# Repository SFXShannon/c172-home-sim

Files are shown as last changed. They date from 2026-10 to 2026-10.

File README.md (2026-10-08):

# C172 Home Sim

3D-printable cockpit controls modelled on the Cessna 172, and a full **172S G1000 dashboard** to mount them in. They're built to drive MSFS from a home-built cockpit.

The goal is **parts that look like the real aircraft's, with simple insides**: printed parts, a few screws, and off-the-shelf sensors such as tactile switches, encoders, slide pots, rockers and toggles.

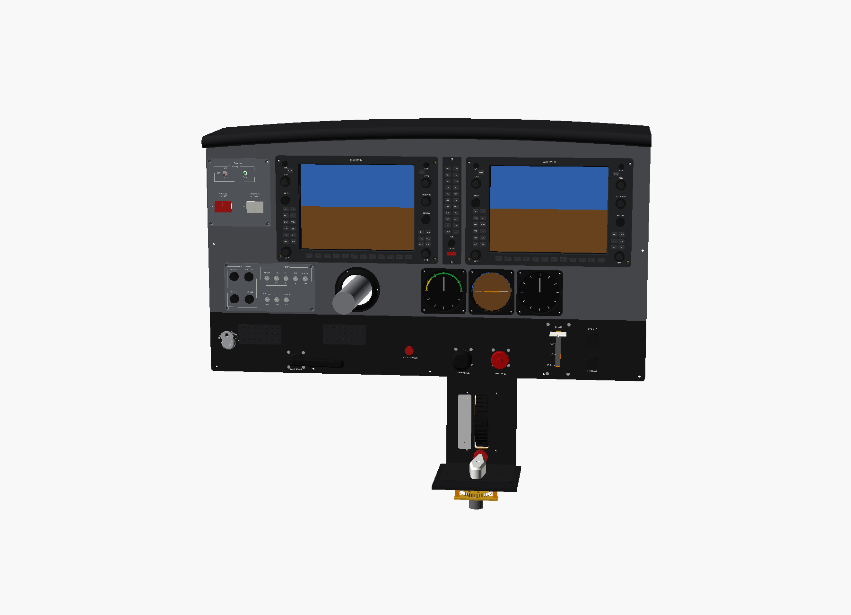
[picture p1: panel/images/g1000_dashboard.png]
G1000 dashboard


**The G1000 dashboard** ([`panel/`](panel#g1000-dashboard)) is a 172S NAV III panel at real scale, shortened to about 32" (810 mm):

- **Glass:** working PFD and MFD bezels with every real key and knob, each with a 10.4" screen behind it, and a working GMA 1347 audio panel.
- **Switches:** the real C-post and lights panels, and the standby instruments.
- **Lower panel:** ignition key, throttle, mixture, flaps, parking brake and cabin knobs.
- **Pedestal:** trim wheel and fuel selector.
- **Yoke:** an opening for the Moza AY210 shaft.

It prints as 9 tiles sized for a 305 mm bed (QIDI Plus4). On a smaller printer, change `bed` and the seams; OpenSCAD warns if a tile won't fit. Or [cut it on a CNC router](panel/dashboard/cnc) from 1/4" plywood in 4 pieces (fits an 800 × 400 mm router such as the FoxAlien XE-PRO 8040).

## See them work

Each animation shows the control from the pilot's seat (left) and from behind the panel with the housing see-through (right), so you can watch the mechanism move. The bezels and switch panels show a close-up on the right instead.

**Parking brake**: pull out, rotate down to set, the lug drops into its notch; rotate back up and the spring pulls it home.

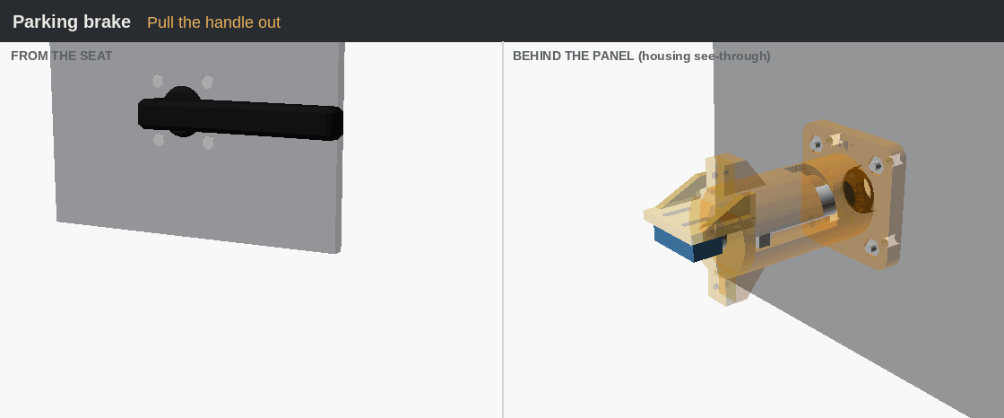
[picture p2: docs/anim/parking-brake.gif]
Parking brake working


**Throttle**: the 8 mm rod slides through the housing and the carriage moves the slide pot. The mixture and prop work the same way.

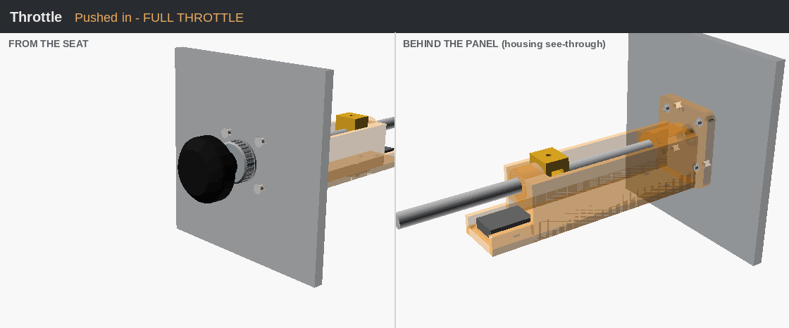
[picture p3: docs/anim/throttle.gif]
Throttle working


**Mixture**

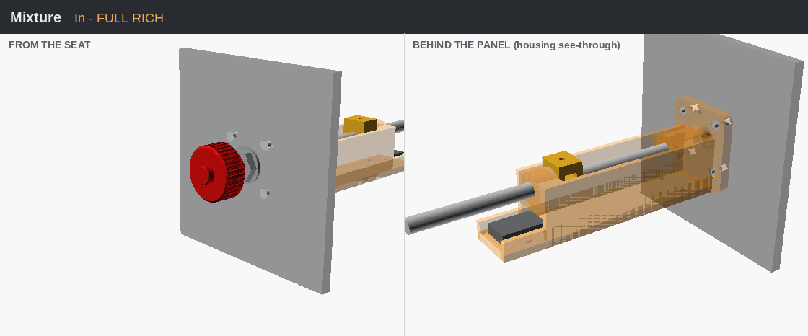
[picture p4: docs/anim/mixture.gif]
Mixture working


**Prop** (optional)

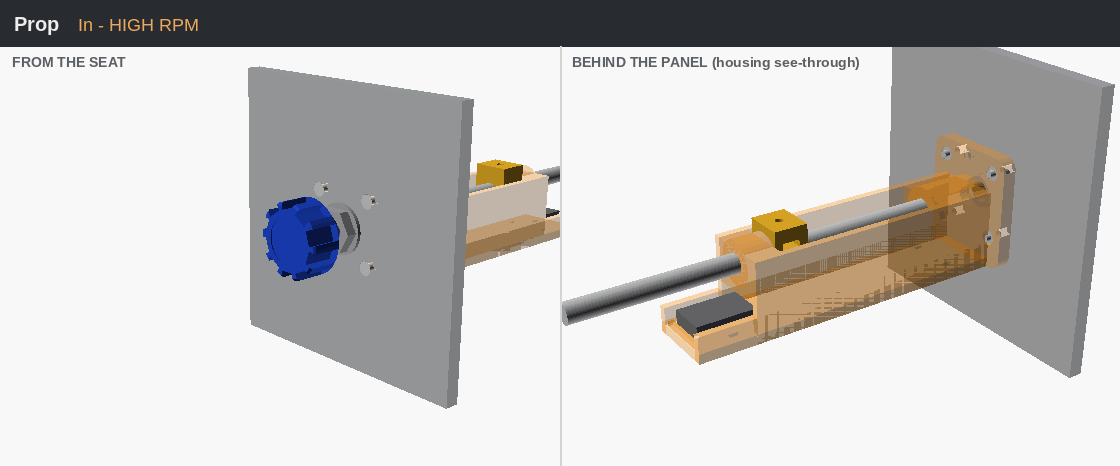
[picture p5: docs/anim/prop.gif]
Prop working


**Elevator trim wheel**: roll the top forward for nose down, back for nose up. The gear on the side of the wheel spins the encoder 3× as fast.

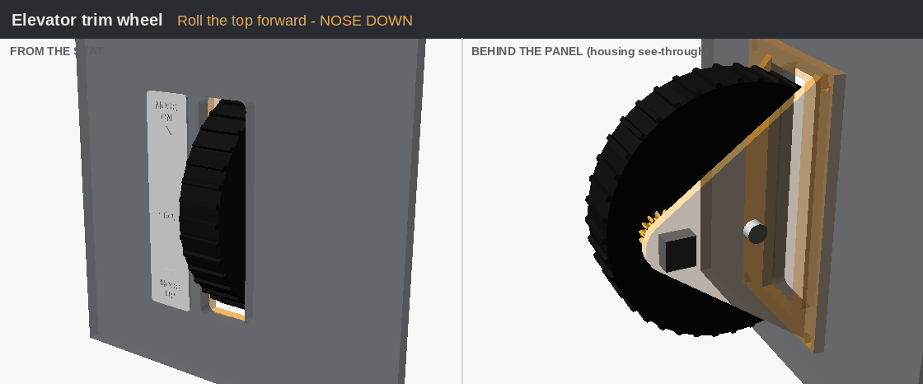
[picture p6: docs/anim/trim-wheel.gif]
Trim wheel working


**Fuel selector**: BOTH → LEFT → BOTH → RIGHT. The small gear on the handle turns the big gear on the rotary switch 1/3 as far, so the handle clicks once per tank position.

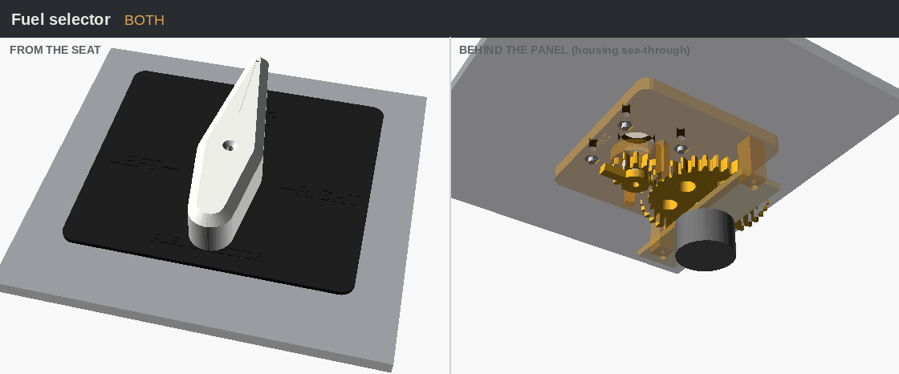
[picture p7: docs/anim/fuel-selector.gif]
Fuel selector working


**Flap lever**: push the handle down through UP → 10° → 20° → FULL. A springy finger on the carriage clicks into a notch at each stop, and the carriage slides a pot like the throttle's.

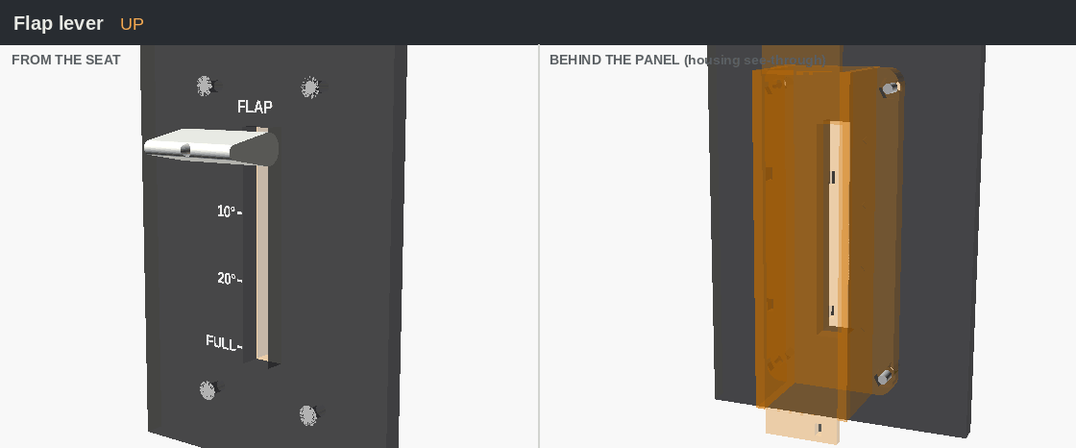
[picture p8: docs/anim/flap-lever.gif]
Flap lever working


**G1000 PFD / MFD bezel**: every key cap is a printed T-shape that presses a 6 mm tactile switch on the plate behind; each knob is an EC11 encoder, and the dual knobs are ALPS dual-shaft encoders. Keys are shown lit while pressed.

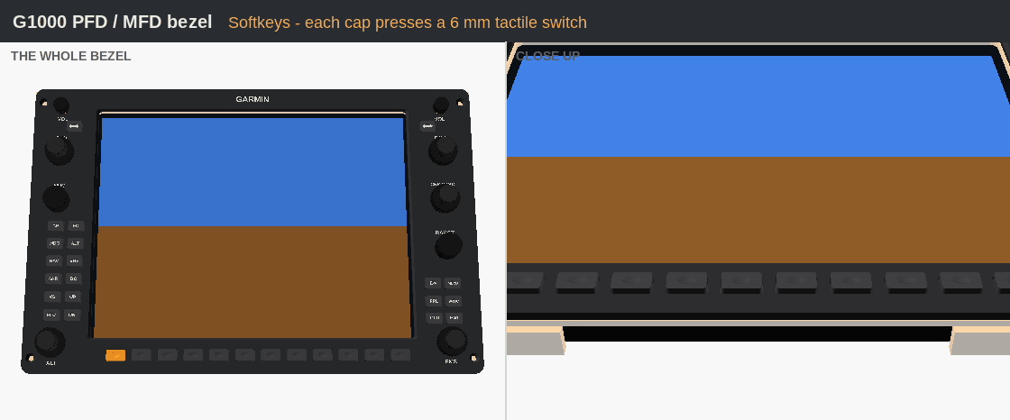
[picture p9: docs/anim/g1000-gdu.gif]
G1000 bezel working


**GMA 1347 audio panel**: same keys and encoder as the G1000 bezel.

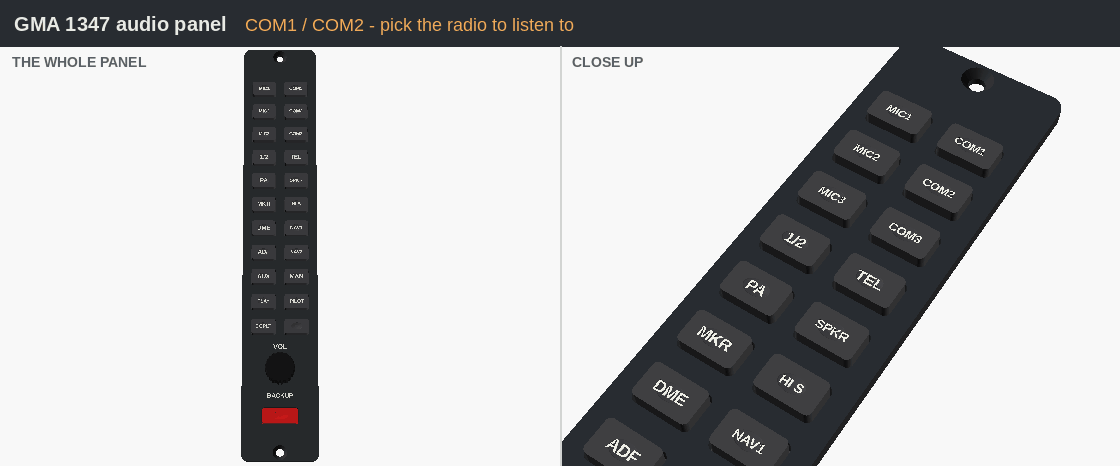
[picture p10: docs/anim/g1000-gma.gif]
Audio panel working


**C-post and lights panels**: off-the-shelf rockers for MASTER and AVIONICS, mini toggles for STBY BATT, lights, fuel pump and pitot heat, and 16 mm pots for the dimmers.

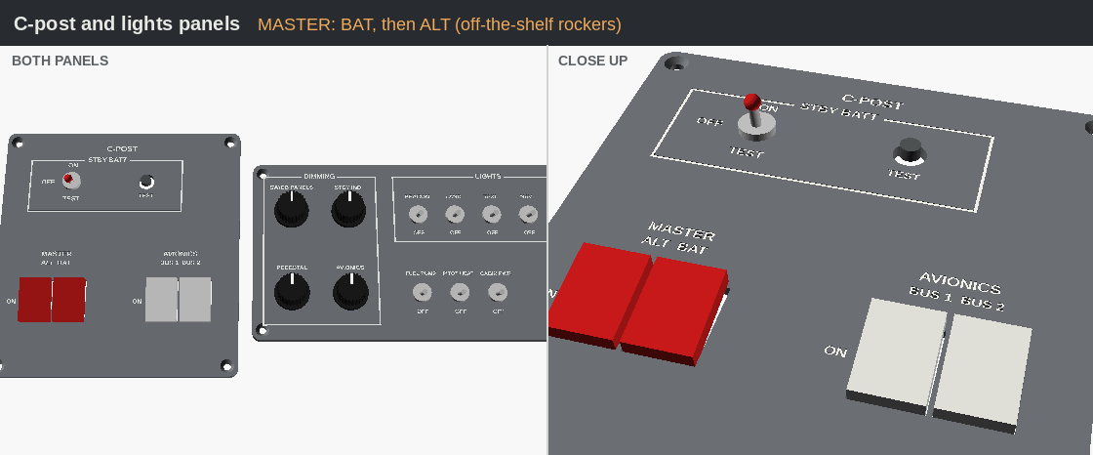
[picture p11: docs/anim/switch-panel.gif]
Switch panels working


**Ignition key**: OFF → R → L → BOTH → START on a rotary switch. The real key springs back from START; this one you turn back to BOTH yourself.

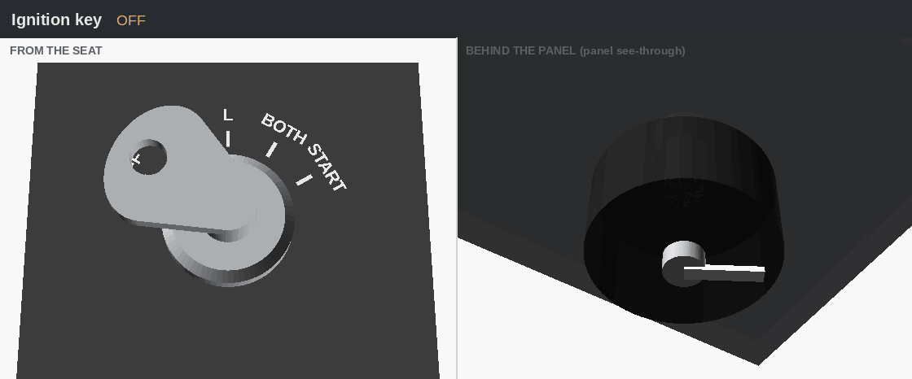
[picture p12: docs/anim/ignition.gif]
Ignition key working


## Controls

| Control | Looks like | Inside | Sensor |
|---|---|---|---|
| [Parking brake](parts/parking-brake) | Black L-lever; pull and rotate down to set | Spring + bayonet slot | Microswitch |
| [Throttle](parts/throttle) | Smooth round knob, knurled friction nut | 8 mm rod, O-ring friction | 128 mm slide pot (100 mm travel) |
| [Mixture](parts/mixture) | Red ribbed vernier knob with lock button | Same as throttle | 128 mm slide pot (100 mm travel) |
| [Prop](parts/prop) (optional) | Blue crenellated knob | Same as throttle | 128 mm slide pot (100 mm travel) |
| [Elevator trim wheel](parts/trim-wheel) | Black ridged wheel in the pedestal, NOSE DN / T.O. / NOSE UP placard | 608 bearings, 3:1 gear | EC11 encoder |
| [Fuel selector](parts/fuel-selector) | Pointer handle on a LEFT / BOTH / RIGHT placard | 3:1 gear to rotary switch | 1P12T rotary switch |
| [Flap lever](parts/flap-lever) | White flap handle, UP / 10 / 20 / FULL scale | Slide with 4 detent clicks | 128 mm slide pot (100 mm travel) |
| [G1000 PFD / MFD](parts/g1000-gdu) | Garmin GDU 1040 bezel, real size and key layout | Printed caps on tactile switches, 10.4" screen | 32 keys, 9 knobs (EC11 / dual EC11) |
| [Audio panel](parts/g1000-gma) | Garmin GMA 1347 | Same as the G1000 bezel | 22 keys, 1 knob |
| [Switch panels](parts/switch-panel) | C-post (STBY BATT, MASTER, AVIONICS) and lights / dimming | Off-the-shelf rockers, toggles and pots | 18 switches, 4 pots |
| [Standby gauges](parts/standby-gauges) | Airspeed, attitude, altimeter with 172S markings | Printed case, paper face | — (look only) |
| [Panel extras](parts/panel-extras) | Ignition key, ALT STATIC / CABIN HT / AIR / FUEL SHUTOFF knobs, breakers, yoke boot | | Rotary switch (key) |
| [Panels](panel) | **G1000 dashboard**, or the simple lower panel + pedestal | Tiled for printing | — |
| [Firmware](firmware) | Pro Micro joystick sketch + [G1000 wiring and MobiFlight guide](firmware/G1000_WIRING.md) | | Pro Micro + 3 × Arduino Mega |

The Moza AY210 yoke has its own buttons and hats, so those aren't modelled. With the base behind the dashboard, its 13-switch panel is out of reach, so the C-post and lights panels take over.

## Panel mounting (same for every control)

Every control bolts behind the panel the same way. Four **M3 countersunk screws** go in from the front, through the control's flange, into **M3 nuts captured in the back of the flange**. The screw heads sit flush, like the real panel. Each control folder has a `panel-template/` (SVG to print 1:1, DXF for laser/CNC) and a `panel_test_plate` STL for test-fitting.

## Moving the controls

On the **G1000 dashboard**, every position is a setting near the top of [`panel/g1000_dashboard.scad`](panel/g1000_dashboard.scad); see [its README](panel#changing-the-layout). The guide below is for the **simple lower panel**, which also has the drag-and-drop layout page.

Every control on the simple printable panel can be moved. The positions are plain numbers in [`panel/c172_panel.scad`](panel/c172_panel.scad). Change them, re-render, and the panel cutouts, countersinks and labels all move with them.

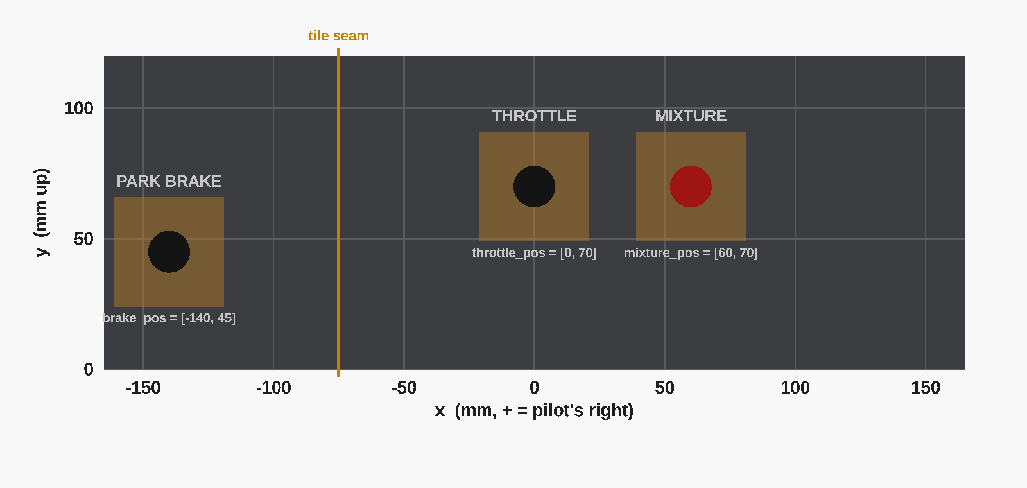
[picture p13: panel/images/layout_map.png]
Layout map


The numbers are in millimetres, as seen from the pilot's seat:
- **x** is how far right of the panel centre (negative = left).
- **y** is how far up from the bottom edge of the panel.

Each control's position is the centre of its knob or shaft.

### What you can move

| Setting | What it moves | Default |
|---|---|---|
| `brake_pos` | Parking brake | `[-140, 45]` |
| `throttle_pos` | Throttle | `[0, 70]` |
| `mixture_pos` | Mixture | `[60, 70]` |
| `mixture_pos_with_prop` | Mixture, used instead when `has_prop = true` | `[110, 70]` |
| `prop_pos` | Prop (only when `has_prop = true`) | `[55, 70]` |
| `has_prop` | Adds the prop control between the throttle and mixture | `false` |
| `pedestal_x` | Moves the whole pedestal (trim wheel + fuel selector) left/right | `30` |
| `lower_w`, `lower_h` | Size of the lower panel | `330`, `120` |
| `pedestal_w`, `pedestal_h`, `floor_d` | Size of the pedestal face and floor plate | `130`, `170`, `150` |
| `yoke_hole` | Cuts a yoke-shaft opening: `[x, y, width, height]`, or `[]` for none | `[]` |
| `labels` | Engraved THROTTLE / MIXTURE / ... labels on or off | `true` |
| `lower_splits` | Where the lower panel is split into print tiles (x positions) | `[-75]` |
| `bed` | Your printer's bed size, so tiles are checked to fit | `305` (QIDI Plus4) |

### Easiest: drag them around in the layout page

Download [`tools/panel-layout.html`](tools/panel-layout.html) (*Raw* → save) and open it in your browser.

- Drag the controls, the pedestal, the tile seams and the yoke opening on a to-scale drawing of the panel.
- It runs the same checks as the OpenSCAD file as you drag (overlaps, edges, seams, bed size). It also warns if the parking brake handle would swing into a knob or hang in front of the pedestal.
- Press **Copy settings** and paste the lines over the layout section of `panel/c172_panel.scad`, then run `scripts/render.sh panel`.
- It can also load the settings from your current file, so you can keep tweaking an existing layout.

### Or in OpenSCAD's Customizer

1. Install [OpenSCAD](https://openscad.org) and open `panel/c172_panel.scad`.
2. Open *Window → Customizer*. The settings above appear under **Layout - lower panel**, **Layout - pedestal** and **Printing**.
3. Change a value, for example `throttle_pos` to `[-10, 75]`. Press **F5** to see the whole cockpit with every control in its new place.
4. Check the console at the bottom for a **WARNING**. The file checks itself and warns if:
   - two controls are too close (their flanges behind the panel need about **46 mm** between centres),
   - a control hangs off the edge of the panel (keep it at least **21 mm** from every edge),
   - a tile seam cuts through a control (move the seam in `lower_splits`),
   - a tile is wider than your bed.
5. When it looks right, pick a piece in `part` (e.g. `lower_tile_1`), press **F6** to render, then **File → Export → STL**. Repeat for each piece you need.

### Or from the command line

Edit the numbers in the file, then rebuild every panel STL, the templates and the preview images:

```bash
scripts/render.sh panel
```

You can also try a layout without editing the file:

```bash
openscad -D 'throttle_pos=[-10,75]' -D 'mixture_pos=[55,75]' -D 'part="preview"' -o test.png panel/c172_panel.scad
```

### Tips

- **Match the sim cockpit.** In VR it matters more than anything that the real knob sits where your hand sees the virtual one. Measure from the sim's cockpit (or your yoke) and move the controls to match.
- **Adding a split:** if you make the panel wider, add more tile seams, e.g. `lower_splits = [-75, 90]`. The panel can be split into up to 3 tiles (`lower_tile_1` to `lower_tile_3`). Put each seam in a gap between controls.
- **Leave the trim wheel and fuel selector on the pedestal.** To move them, change `pedestal_x`, `pedestal_w`, `pedestal_h` or `floor_d`; the parts stay centred on their plates.
- **Pre-made controls.** The individual controls (`parts/...`) don't need re-rendering when you move them; only the panel changes.

## Layout

```
common/            shared settings (panel thickness, fit, M3 hardware, mount pattern, gears)
  push_pull.scad   shared throttle / mixture / prop mechanism
parts/<control>/
  <control>.scad   parametric source (OpenSCAD Customizer)
  stl/             print-ready STLs, already in print orientation
  panel-template/  cutout drawing
  images/          renders
  README.md        parts list, printing, assembly, wiring, MSFS binding
panel/             g1000_dashboard.scad (full dashboard) + c172_panel.scad (simple lower panel)
  dashboard/       dashboard tiles, glareshield, pedestal STLs + full-size templates
    cnc/           CNC router files (layered DXF / SVG) for cutting the panel from 1/4" sheet
firmware/          Arduino Pro Micro sketch, G1000 wiring / MobiFlight guide (G1000_WIRING.md)
tools/             panel-layout.html: drag-and-drop panel layout page
scripts/render.sh  regenerate STLs/templates for the controls
scripts/make_cnc.py  regenerate the CNC router files
scripts/place_splices.py  find room for the splice plates that join the panel pieces
```

## Rebuilding after changes

```bash
scripts/render.sh                  # all controls + both panels
scripts/render.sh throttle         # one control
scripts/render.sh dashboard        # the G1000 dashboard tiles, glareshield, pedestal
scripts/render.sh panel            # the simple lower panel
PANEL=3 scripts/render.sh          # for a 3 mm panel
```

Everything needs OpenSCAD 2021.01 or newer. To re-make the animations above after a change, run `python3 scripts/make_gifs.py` (needs Pillow). The script runs on Linux, macOS, or Windows with Git Bash or WSL.

## Status

Every moving part has been checked in OpenSCAD for collisions through its full range of movement, but **nothing has been test-printed yet**. Expect to tune `clearance` for your printer. Dimensions are approximated from photos of real 172 parts, not factory drawings.

## License

MIT. See [LICENSE](LICENSE).

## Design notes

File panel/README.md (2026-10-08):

# Printable Panels

There are two panel options:

1. **[G1000 dashboard](#g1000-dashboard)**: the full 172S G1000 panel, shortened to about 32" (810 mm), with every control. This is the main one.
2. **[Simple lower panel](#simple-lower-panel)**: just the parking brake, throttle, mixture (and prop) plus the pedestal. Good for testing the controls before building the whole dashboard.

---

## G1000 dashboard

G1000 dashboard

| Behind the panel (AY210 base shown as a grey box) | Layout and print tiles |
|---|---|
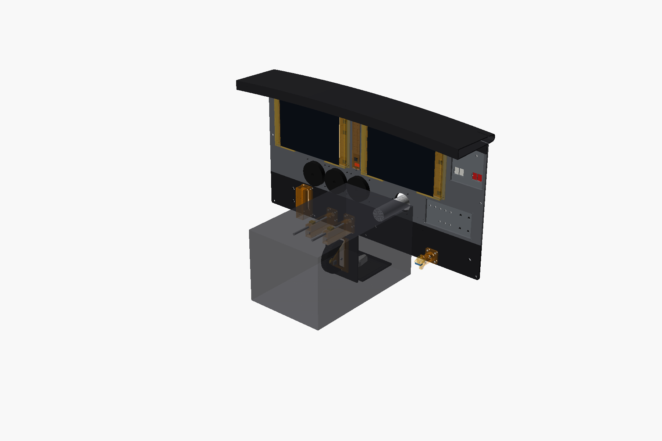
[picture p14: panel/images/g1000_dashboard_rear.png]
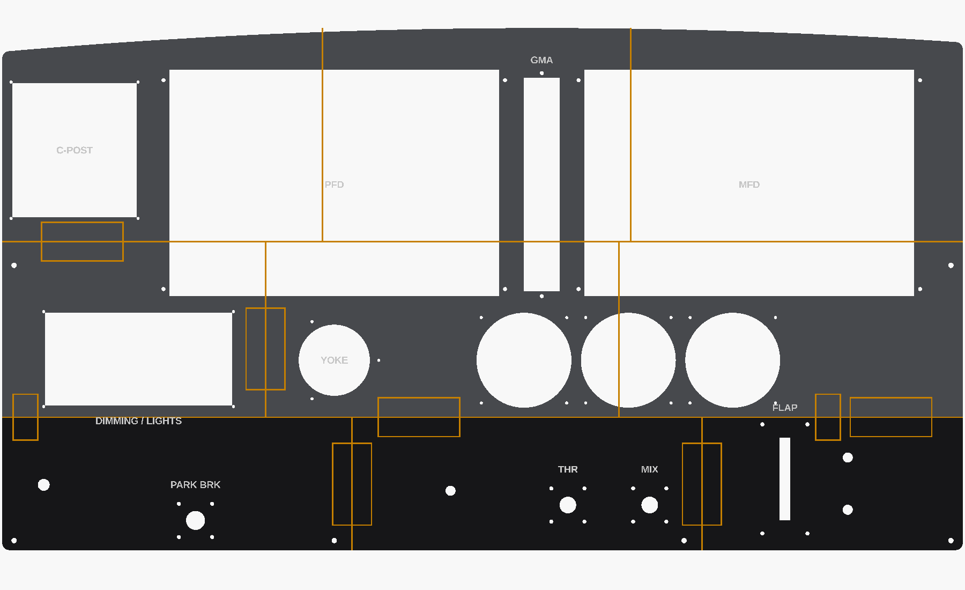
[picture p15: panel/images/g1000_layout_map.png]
|  |  |

Laid out from photos of the real 172S NAV III panel and kept at real scale; only the copilot side is cut off.

| Area | What's there |
|---|---|
| Upper (grey) | C-post switches, PFD, GMA 1347 audio panel, MFD, dimming/lights panel, yoke shaft opening, standby airspeed / attitude / altimeter |
| Lower (black) | Ignition key, circuit breakers (look only), parking brake, ALT STATIC AIR, throttle, mixture, flap lever, cabin heat / cabin air |
| Pedestal | Elevator trim wheel, fuel shutoff knob, floor plate with the fuel selector |
| Top | Glareshield in 4 segments |

### Printing it

- **Tiles:** 9 of them, 3 per row, sized for a 305 × 305 mm bed (QIDI Plus4). Row L (lower) in black; rows M and U in grey. Print them **front face down**. The largest is 298 × 148 mm. For a smaller printer, set `bed` and move the seams in `lower_splits`, `mid_splits` and `upper_splits` (up to 5 tiles per row); OpenSCAD warns if a tile is too wide.
- **Joining:** see [Joining the pieces](#joining-the-pieces) below.
- **Or cut it on a CNC router:** [`dashboard/cnc`](dashboard/cnc) has layered DXF / SVG files for cutting the panel from 1/4" plywood or MDF in 4 pieces (plus the pedestal plates), sized for an 800 × 400 mm router like the FoxAlien XE-PRO 8040.
- **Glareshield:** 4 segments. Print them upside down with tree supports, or use them as formers and cover with foam and vinyl like the real padded one.
- **Pedestal:** the face and floor plates.
- **Full-size template:** [`dashboard/templates/`](dashboard/templates) has the whole panel as one SVG/DXF (front view), for a big laser or to print and check the layout.
- **Mounting to your frame:** 4.5 mm holes along the bottom edge and the sides take #8 / M4 screws.

STLs are in [`dashboard/stl/`](dashboard/stl). After changing anything, regenerate them with `scripts/render.sh dashboard`.

### Fitting it to your Moza AY210

The yoke shaft comes through a 60 mm hole in front of the pilot (`yoke_pos`, default 160 mm up from the panel bottom), with a printed boot ring round it.

- **Shaft height:** set `moza_shaft_h` to the height of the AY210 shaft above the bottom of its base. Measure yours: Moza doesn't publish it, and the default 150 mm is a guess. Then set the panel height so the hole lines up with the shaft.
- **Clearance:** the base sits behind the panel. `moza_front` is the gap from the panel back to the base's front face; keep it above about 80 mm so the parking brake and the PFD screen clear it. The file warns if they'd collide.
- **Base switches:** the AY210's own 13-switch panel will be out of reach behind the dashboard, so the C-post and lights panel take over.

### Changing the layout

Every position is a setting near the top of [`g1000_dashboard.scad`](g1000_dashboard.scad), in mm from the pilot's centre line (`x`, + = right) and up from the panel bottom (`y`): `pfd_pos`, `gma_pos`, `mfd_pos`, `cpost_pos`, `lights_pos`, `gauge_*`, `yoke_pos`, `ignition_pos`, `brake_pos`, `throttle_pos`, `mixture_pos`, `flap_pos`, and so on. You can also change the panel width (`x_left`, `x_right`), the top arch, the tile seams and your `bed` size. OpenSCAD warns if a tile won't fit your printer.

---

## Joining the pieces

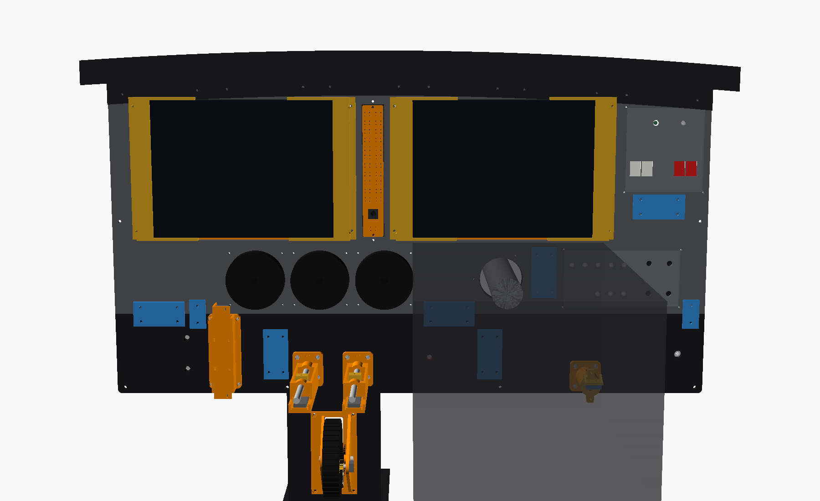
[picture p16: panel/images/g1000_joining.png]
Back of the dashboard: splice plates in blue


The tiles (or CNC pieces) butt together and are joined from the back in three ways:

1. **Splice plates** (blue above) straddle the seams and the two row joints. Each screws into **blind pilot holes** already in the back of the pieces, so nothing shows on the front. `scripts/place_splices.py` finds room for them clear of everything mounted behind the panel and writes their positions to [`splices.scad`](splices.scad). For the printed tiles that's:
   - 6 × `splice` (34 × 70 mm, 4 screws), across the lower seams, the seam beside the yoke, and the two row joints
   - 2 × `splice_small` (40 × 22 mm, 2 screws), for tight spots on the lower/middle row joint

   Print them flat, 4 mm thick (`panel/dashboard/stl/splice.stl`, `splice_small.stl`). Spread glue on the plate (CA or epoxy for PLA/PETG), press it on over its holes, and drive **M3 × 8** screws (4 mm into the panel; longer ones come through the front). The same plate turns 90° for the horizontal joints.
2. **The bezels and gauges** cover the seams that have no room for a plate (through the PFD, the MFD and the attitude gauge). Their screws go into the pieces on both sides, so each one acts as a splice.
3. **The glareshield** is split at different places from the upper tiles (`glareshield_splits`; by default halfway along each tile). Each glareshield piece screws into the tiles on both sides of a seam, which ties the top edge.

**Order:** lay the tiles face down on a flat table and glue and screw the splice plates. Then stand the panel up and fit the bezels, gauges and glareshield. Last, screw the panel to your frame through the frame holes along the bottom and sides.

If you move controls or change the seams, run `python3 scripts/place_splices.py` (needs `pip install shapely`) before re-rendering; `scripts/render.sh dashboard` does it for you. It prints each seam's plates, and says when a seam has no room for one.

## Simple lower panel

Panel pieces with every control's cutouts, mounting holes and countersinks already in place. The layout follows the 172S lower panel and centre pedestal.

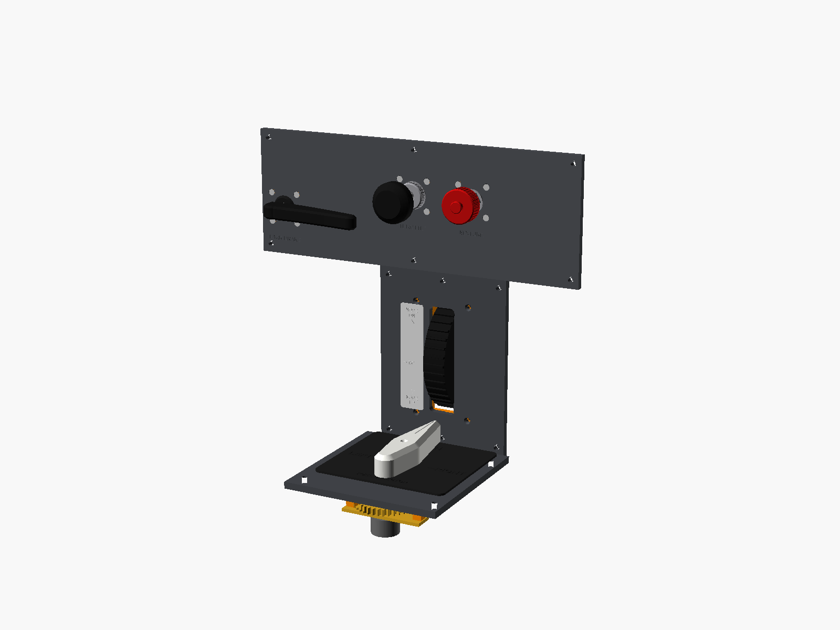
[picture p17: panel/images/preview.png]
preview


| With the optional prop control | Behind the panel |
|---|---|
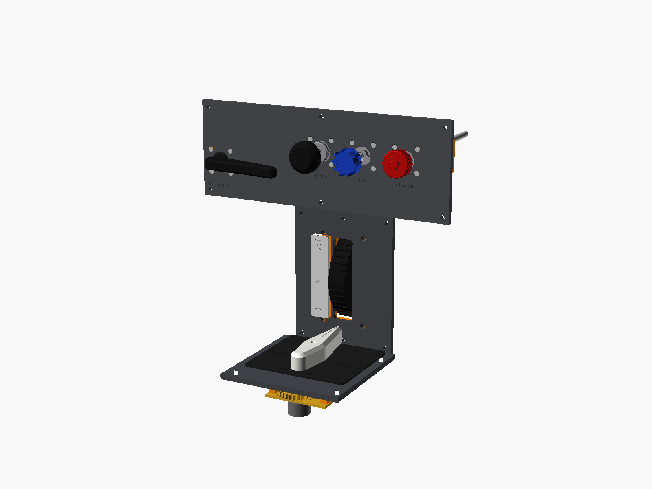
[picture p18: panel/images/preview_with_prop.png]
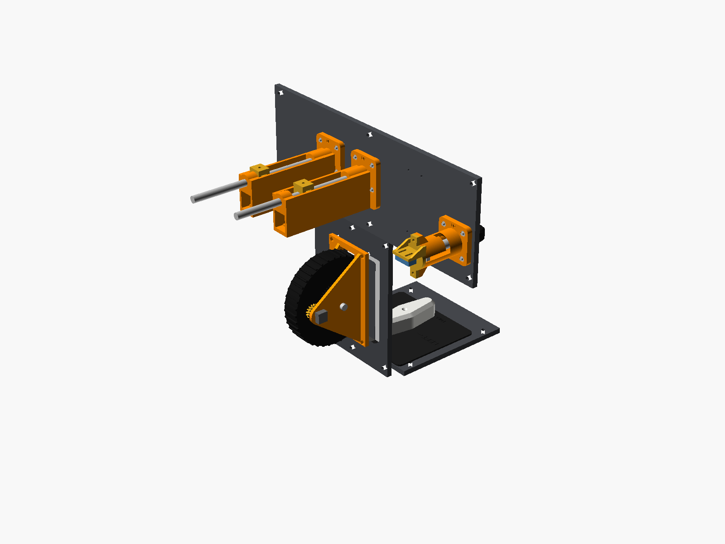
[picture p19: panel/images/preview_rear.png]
|  |  |

## Pieces

| Piece | What's on it | Size | STL |
|---|---|---|---|
| Lower panel | Parking brake, throttle, (prop), mixture, engraved labels | 330 × 120 mm, split into 2 tiles | `lower_tile_1`, `lower_tile_2` + `splice` |
| Pedestal face | Trim wheel slot + placard outline | 130 × 170 mm | `pedestal` |
| Pedestal floor | Fuel selector | 150 × 150 mm | `floor` |

- **Thickness:** all pieces are `panel_thickness` thick (6.35 mm by default, set in `common/sim_common.scad`).
- **Printing:** print **front face down** for a smooth face; the engraved labels print correctly that way.
- **Joining the lower panel:** the tiles butt together. Glue the `splice` strip across the seam on the back, plus 4 × M3 × 8 screws into the blind pilot holes.
- **Mounting:** the 4.5 mm holes around the edges are for #8 or M4 screws into your frame.
- **Cutting from plywood instead:** [`templates/`](templates) has full-size SVG and DXF files (front view) for a laser or CNC, or to print and drill through.

## Changing the layout

The easiest way is the drag-and-drop page [`tools/panel-layout.html`](../tools/panel-layout.html). See **[Moving the controls](../README.md#moving-the-controls)** in the main README for the full guide.

Layout map

Open `c172_panel.scad` in OpenSCAD and use the Customizer:

- **Control positions:** `brake_pos`, `throttle_pos`, `prop_pos`, `mixture_pos`, in mm right of panel centre and up from the panel bottom.
- **Prop:** `has_prop` adds the blue prop knob between the throttle and mixture.
- **Yoke:** `yoke_hole = [x, y, w, h]` cuts an opening for a yoke shaft. Your Moza AY210 sits on the desk, so leave it empty unless the yoke shaft has to pass through this panel.
- **Labels:** `labels` turns the engraved labels on or off.
- **Bed size:** `bed` (your print bed size) and `lower_splits` (where tiles split). OpenSCAD warns if a tile is too big.

The positions are approximate 172S proportions taken from photos, not from factory drawings. Move them to suit your seat, yoke and monitor.

## Not included (already on your Moza AY210)

The AY210 base has its own 13-switch panel, and the yoke has the buttons and hats. So master, avionics, lights and magneto switches aren't modelled here.

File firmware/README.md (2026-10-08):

# Firmware: whole panel as one USB controller

[`c172_panel/c172_panel.ino`](c172_panel/c172_panel.ino) turns an **Arduino Pro Micro** (or Leonardo) into a game controller with 4 axes and 16 buttons. Windows and MSFS see it as a joystick, so no extra software is needed.

As far as I know, the GP-Wiz is a button-only board, so it can't read the throttle, mixture and prop potentiometers. One Pro Micro (about $10) handles everything on this panel.

| Input | Pin | Shows up as |
|---|---|---|
| Throttle pot wiper | A0 | X axis |
| Mixture pot wiper | A1 | Y axis |
| Prop pot wiper | A2 | Z axis (set `HAS_PROP = true`) |
| Flap lever pot wiper | A3 | Rx axis (set `HAS_FLAPS = true`) |
| Parking brake microswitch (COM → GND, NC → pin) | 2 | Button 1 held while set; 2 = "just set" pulse; 3 = "just released" pulse |
| Fuel selector LEFT / BOTH / RIGHT / OFF (common → GND) | 3 / 4 / 5 / 6 | Buttons 4 / 5 / 6 / 7 held |
| Trim encoder A / B (middle → GND) | 7 / 8 | Button 8 pulse per click nose down, button 9 nose up |

Pots: wire the two ends to VCC and GND, and the wiper to the pin.

## Install

1. Install the Arduino IDE.
2. Add the **Joystick** library by Matthew Heironimus: download https://github.com/MHeironimus/ArduinoJoystickLibrary as a ZIP, then use *Sketch → Include Library → Add .ZIP Library*.
3. Open `c172_panel.ino`, choose the board **Arduino Leonardo** (this works for the Pro Micro too) and upload.
4. **Calibrate:** move the throttle, mixture, prop and flap lever end to end once. The levers only use about 60 mm of the 128 mm pots' 100 mm travel, so the sketch learns where each one stops and stretches that to the full axis. It saves the ranges in EEPROM, so you only do this once. To start over, set `RESET_CALIBRATION = true`, upload, set it back to `false` and upload again.
5. In Windows, open *Set up USB game controllers* to check the axes and buttons.

The settings at the top of the sketch reverse axes or the trim direction, and set the number of encoder steps per click.

The sketch passes a syntax check but hasn't been tested on real hardware yet.

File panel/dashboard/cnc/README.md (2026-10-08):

# Cutting the dashboard on a CNC router

Files for cutting the G1000 dashboard panel from **1/4" (6.35 mm) plywood or MDF** on an 800 × 400 mm router (FoxAlien XE-PRO with the 8040 extension, or similar), instead of printing the tiles.

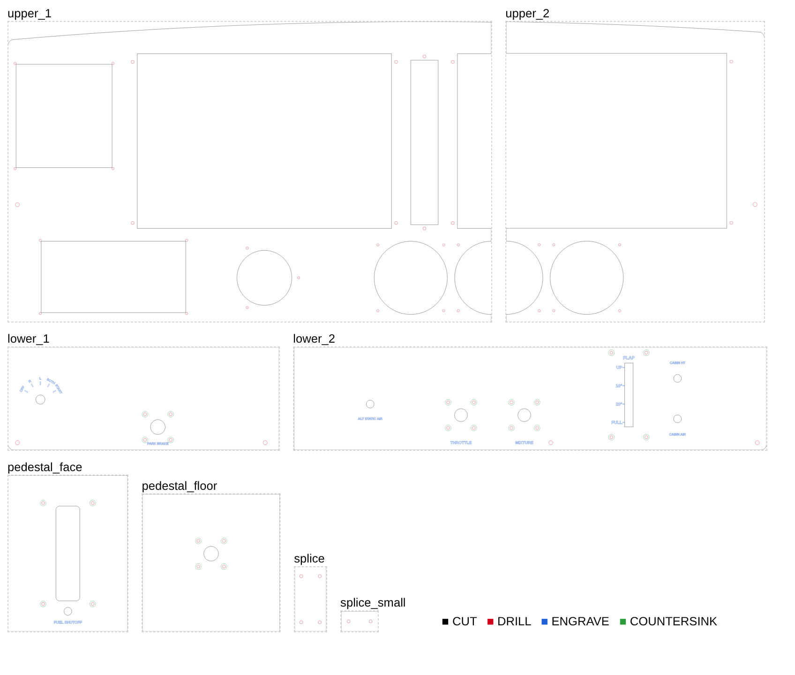
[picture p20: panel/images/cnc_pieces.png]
CNC pieces


## The pieces

| File | Piece | Size (mm) |
|---|---|---|
| `upper_1` | Upper (grey) panel, left: C-post, PFD, audio panel, lights panel, yoke, airspeed + half the attitude gauge | 528 × 328 |
| `upper_2` | Upper panel, right: MFD, other half of the attitude gauge, altimeter | 282 × 327 |
| `lower_1` | Lower (black) panel, left: ignition, parking brake | 295 × 112 |
| `lower_2` | Lower panel, right: alt static, throttle, mixture, flaps, cabin heat / air | 515 × 112 |
| `pedestal_face` | Pedestal: trim wheel, fuel shutoff | 130 × 170 |
| `pedestal_floor` | Pedestal floor: fuel selector | 150 × 150 |
| `splice` | Joining plate, 34 × 70 (cut 3) | 34 × 70 |
| `splice_small` | Small joining plate, 40 × 22 (cut 3) | 40 × 22 |

The full panel is 810 mm wide, a little more than the 800 mm X travel, so the lower and upper panels are each cut in two. The upper seam runs through the attitude gauge and the MFD: both bezels screw into both pieces and tie them together. Splice plates on the back join the lower seam and the joint between the lower and upper panels.

## Files

Each piece has a `.dxf` and an `.svg` with the same content. Use whichever your CAM program imports better. Units are mm, viewed from the front, with the piece's lower-left corner at 0,0. Each file has one layer (DXF) or colour (SVG) per operation:

| Layer | Colour | What it is | Suggested tool |
|---|---|---|---|
| `CUT` | black | Outline (outside profile) and openings (inside profiles), cut through | 1/8" (3.175 mm) 2-flute upcut or compression end mill |
| `DRILL` | red | Small through holes as circles: M3 clearance (3.4 mm), pilot (2.6 mm), frame screws (4.5 mm) | Peck-drill with the 1/8" bit, then open to size by hand |
| `ENGRAVE` | blue | Labels: THROTTLE, MIXTURE, flap scale, ignition positions, and so on | 60° or 90° V-bit, 0.6 mm deep |
| `COUNTERSINK` | green | Circles the size of an M3 countersunk head (6.4 mm), around the control mounting holes | 90° V-bit plunged 3.2 mm at the centre, or a countersink bit by hand |

`<piece>_back.dxf` / `.svg` hold the **blind pilot holes on the back**, for the G1000 screen cradles, the splice plates and the glareshield. They're mirrored left to right and include the outline, so they line up after you flip the piece. Drill them **4 mm deep, not through**. If you'd rather not flip pieces on the machine, measure them from the outline and drill them by hand with a depth stop.

## Cutting order (front face up)

1. Clamp a sheet at least 20 mm bigger than the piece on every side, so the clamps stay clear of the outline. Zero X/Y at the lower-left corner of the piece and Z on the top of the sheet.
2. **ENGRAVE** first, while the sheet is flat and solid.
3. **COUNTERSINK**, then **DRILL**.
4. **CUT**: the openings first, then the outline with tabs. In 1/4" plywood, take about 1.5 mm per pass and cut 0.3 mm into the spoil board. A starting point for a 1/8" end mill is 800 mm/min. Listen to the cut and adjust for your spindle and wood.
5. Clean up the tabs. Open the M3 clearance holes to 3.4–3.5 mm and the frame holes to 4.5 mm with a hand drill.

Inside corners of the openings come out rounded to the bit radius. That's fine with a 1/8" bit: everything that sits in an opening has corners rounded at least that much. Don't use a bigger bit for the openings.

## Putting it together

- **Splice plates:** lay the pieces face down on a flat table. Glue each plate over its blind pilot holes (they show where it goes: 1 across the lower seam, 5 along the lower/upper joint) and screw it down with **#4 × 3/8" wood screws** or **M3 × 10** (any longer and they come through the front).
- **Upper seam:** fit the attitude gauge and the MFD bezel; their screws hold the two upper pieces in line. The printed glareshield crosses it too and screws into both pieces.
- **Frame:** screw the panel to your frame through the frame holes along the bottom and sides.
- **Finish:** paint the lower panel black and the upper panel grey (the 172S colours), then fill the engraved labels with white paint and sand the face lightly.
- **Screws:** the controls and bezels use the same M3 screws as the printed tiles. In wood, M3 machine screws into the 2.6 mm pilot holes hold well enough, or use #4 wood screws.

## Changing it

The splits and the hole size that counts as "drill" are settings in [`../../g1000_dashboard.scad`](../../g1000_dashboard.scad) under **CNC router**: `cnc_lower_split`, `cnc_upper_split`, `cnc_drill_max`. Every control position in the dashboard file feeds into these files too. After a change, run:

```bash
python3 scripts/make_cnc.py
```

(It needs OpenSCAD. `scripts/render.sh dashboard` runs it as well.)

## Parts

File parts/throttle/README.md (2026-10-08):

# Throttle (and the shared push-pull mechanism)

Throttle, mixture and prop all use the same simple mechanism. Only the knob and the panel nut change:

| Control | Knob | Panel nut | Folder |
|---|---|---|---|
| **Throttle** | Smooth round knob with a flat face. Print it black, or cream for older 172s | Knurled friction-lock nut | here |
| **Mixture** | Red, fine ribs around the edge, lock button in the centre (vernier style) | Hex bushing nut | [`../mixture`](../mixture) |
| **Prop** | Blue, crenellated edge (172RG / 182 / constant-speed) | Hex bushing nut | [`../prop`](../prop) |

throttle working

| Pushed in | Pulled out | Behind the panel |
|---|---|---|
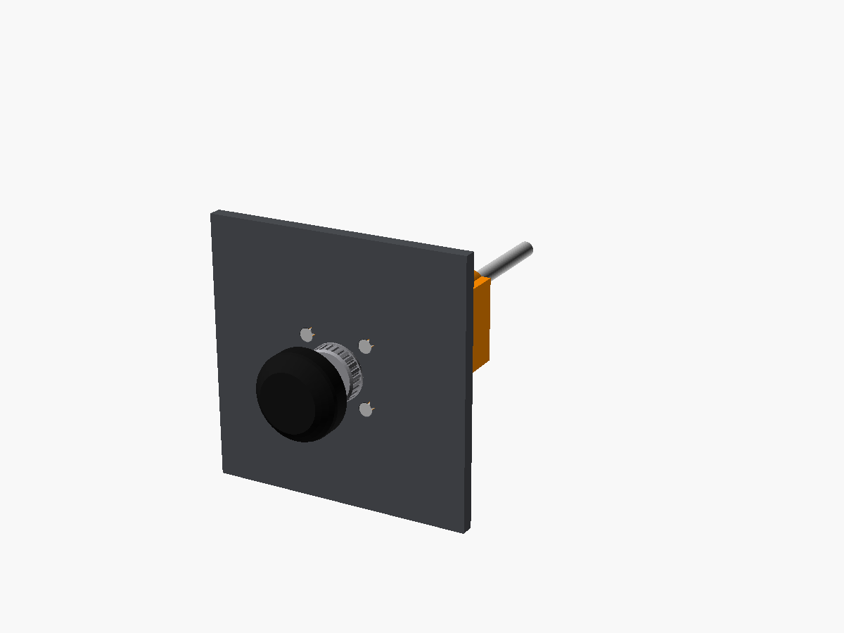
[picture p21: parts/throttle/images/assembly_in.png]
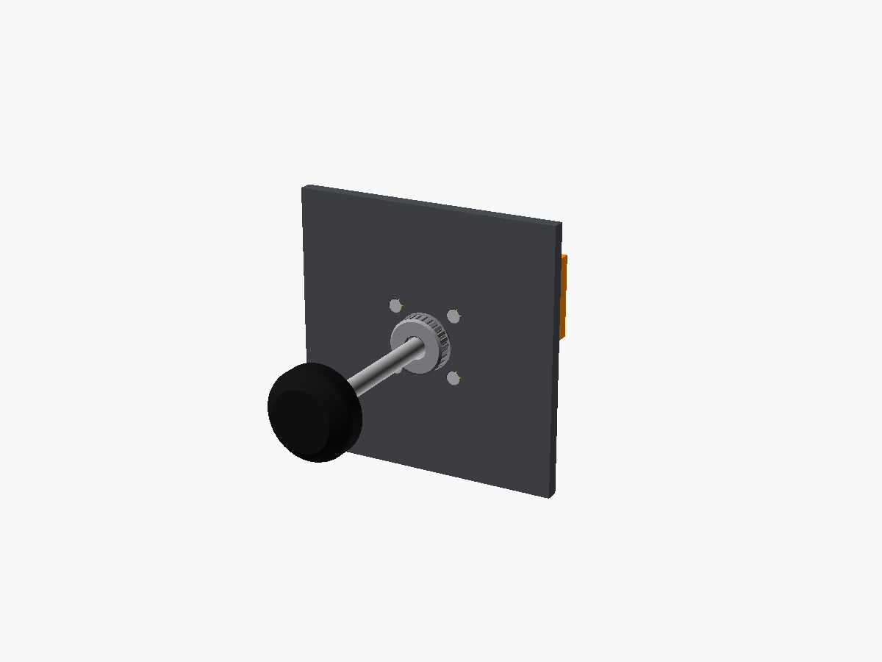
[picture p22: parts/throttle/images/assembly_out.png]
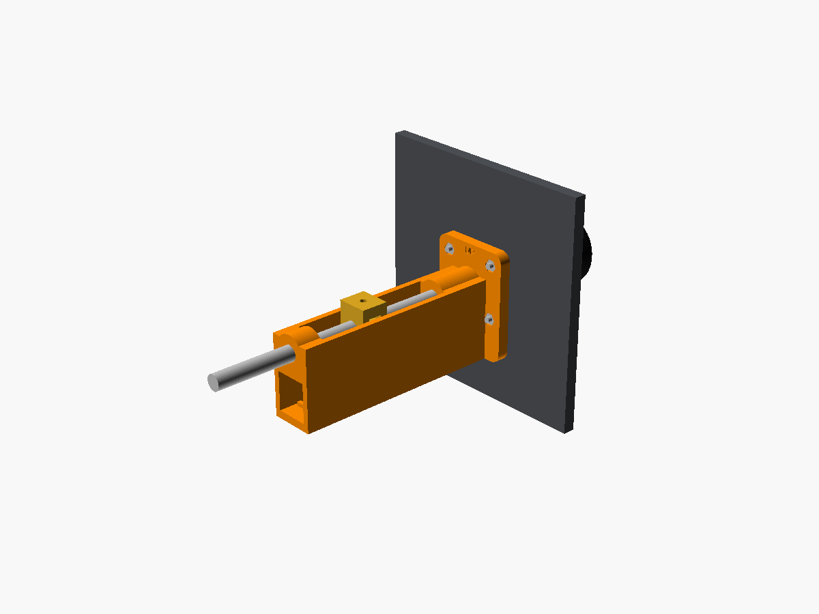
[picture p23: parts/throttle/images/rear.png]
|  |  |  |

## How it works (kept simple)

- **Shaft:** an 8 mm smooth steel rod, the same rod 3D printers use, so it's cheap, straight and smooth. It slides through a printed U-channel bolted behind the panel.
- **Friction:** an 8 × 2 mm O-ring in the front bushing holds the knob wherever you leave it, like the friction lock on the real throttle.
- **Sensor:** a printed carriage clamped to the rod with an M3 set screw pushes the lever of a slide potentiometer that sits in the bottom of the channel. It's drawn for the Fielect **128 mm** fader (10K linear, 100 mm travel, body 128 × 15.7 × 6.9 mm). The lever height (`pot_lever_h = 5`) is read off a photo, so measure yours.
- **Travel:** 60 mm (`control_travel`), set by the bushings, about like the real knob. That uses the middle 60 % of the pot's travel; the Pro Micro sketch learns the range and stretches it to the full axis. The housing reaches about 140 mm behind the panel.

## Parts list (per control)

| Qty | Item | Notes |
|---|---|---|
| 1 each | Printed: `knob`, `escutcheon`, `housing`, `carriage` | [`stl/`](stl) |
| 1 | 8 mm smooth rod, ~215 mm | OpenSCAD prints the exact length. Cut it with a hacksaw and file the ends. |
| 1 | Slide potentiometer, 10 kΩ linear, 128 mm long / 100 mm travel (e.g. Fielect 128 mm fader) | Sits in the channel floor. Measure yours and set `pot_len`, `pot_w`, `pot_h`, `pot_lever_h`, `pot_travel` if they differ (a 60 mm pot works too: `pot_len = 76`, `pot_travel = 60`) |
| 1 | O-ring, 8 mm ID × 2 mm | For friction |
| 1 + 1 | M3 × 8 set screw + M3 nut | Carriage clamp |
| 4 + 4 | M3 × 14 countersunk screws + M3 nuts | Panel mount |
| 2 | Zip ties | Hold the pot down |

## Printing

No supports needed.

- **housing:** lies on its floor. If the 8 mm bores come out tight, ream them with an 8.5 mm drill.
- **knob:** the throttle prints face-down; the mixture and prop print back-down. For the mixture, use a colour change to make the button black, or paint it.
- **escutcheon:** prints front face down.

## Assembly

1. Seat the O-ring in the groove inside the front bushing, then zip-tie the pot into the channel floor with its lever pointing up.
2. Push the rod in from the front through the bushing. Slide the carriage on with its slot over the pot lever, then push the rod on through the rear bushing.
3. Push the rod fully in and slide the carriage back against the rear bushing. Tighten the set screw.
4. Bolt the housing behind the panel with "UP" at the top. Push the escutcheon into the hole, then glue the knob onto the rod (CA or epoxy).

## Wiring and sim

Wire the pot ends to 5V and GND, and the wiper to an analog input. With the Pro Micro sketch in [`/firmware`](../../firmware): throttle on A0 (X axis), mixture on A1 (Y axis), prop on A2 (Z axis).

In MSFS, bind the axes to *Throttle axis*, *Mixture axis* and *Propeller axis*. If one works backwards, use the reverse option in MSFS or the `REVERSE_` setting in the sketch.

**Note:** the GP-Wiz is a button board, so it can't read these pots. That's why the Pro Micro sketch is included.

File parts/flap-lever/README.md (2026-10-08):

# Flap lever

The 172S flap lever: a small white handle that moves up and down a slot with clicks at **UP, 10°, 20° and FULL**. The scale is engraved in the dashboard beside it.

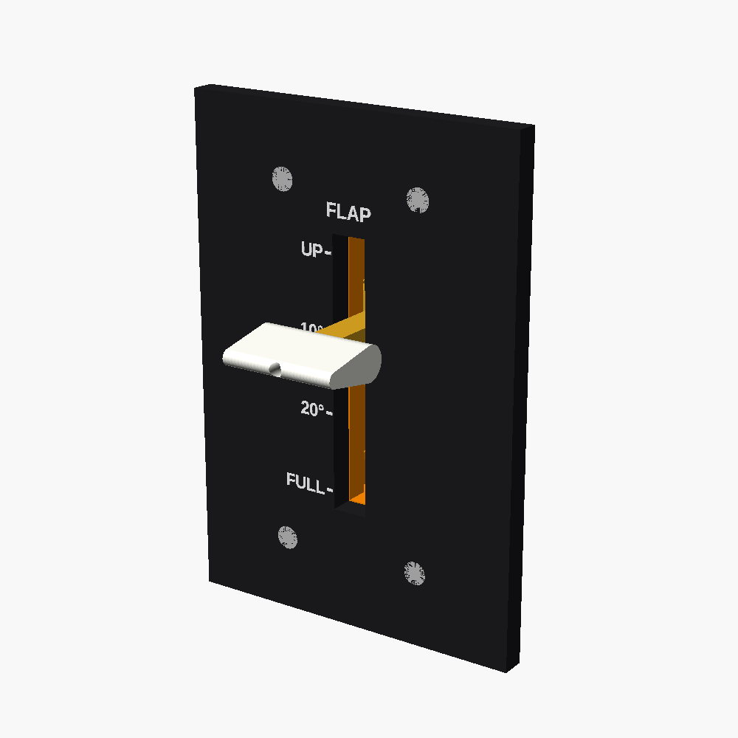
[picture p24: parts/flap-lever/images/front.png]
Flap lever


Flap lever working

## How it works (kept simple)

- **Housing:** a printed channel bolted behind the panel (4 × M3 countersunk screws into captive nuts).
- **Carriage:** slides in the channel. Its stem passes through the slot to the handle.
- **Detents:** a springy printed finger on the carriage clicks into 4 notches 20 mm apart.
- **Sensor:** the carriage drives the same **128 mm slide pot** as the throttle (it uses about 60 mm of its 100 mm travel; the pot is longer than the housing, so two narrow channels carry its ends). Wire it to A3 on the Pro Micro (set `HAS_FLAPS = true` in the sketch) and bind the Rx axis to *Flaps axis* in MSFS.

## Parts list

| Qty | Item |
|---|---|
| 1 each | Printed `housing`, `carriage`, `handle` (white) |
| 1 | Slide pot, 10 kΩ linear, 128 mm long / 100 mm travel (set `pot_len`, `pot_travel` etc. for another size) |
| 4 + 4 | M3 × 14 countersunk screws + nuts |
| 1 | M3 × 12 screw (handle to stem) |
| 2 | Zip ties (pot) |

Print the carriage in PETG if you can; the detent finger lasts longer than in PLA. If the clicks are too stiff or too soft, sand the bump or change the gap in `carriage()`.

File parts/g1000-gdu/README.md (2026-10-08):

# G1000 PFD / MFD bezel (GDU 1040)

A working copy of the Garmin GDU 1040 bezel at real size (300 × 196 mm), with the real key and knob layout. Build two: one for the PFD and one for the MFD (the real units are identical).

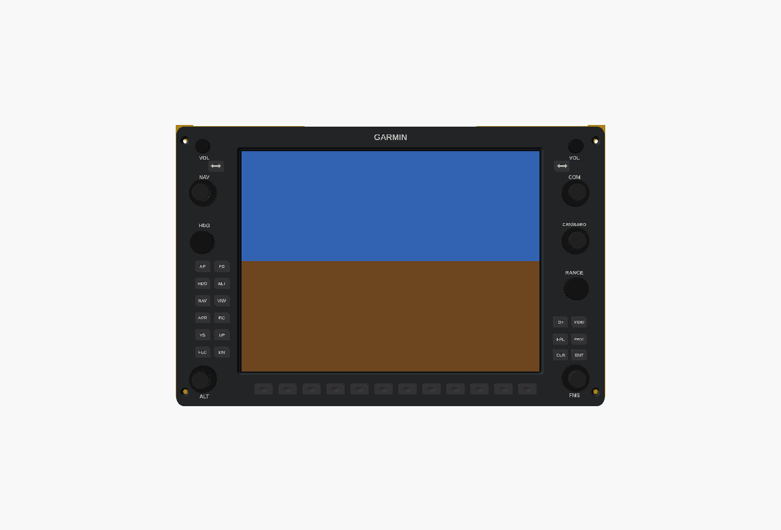
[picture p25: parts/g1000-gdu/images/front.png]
GDU 1040 bezel


G1000 bezel working

| Behind the panel | Exploded |
|---|---|
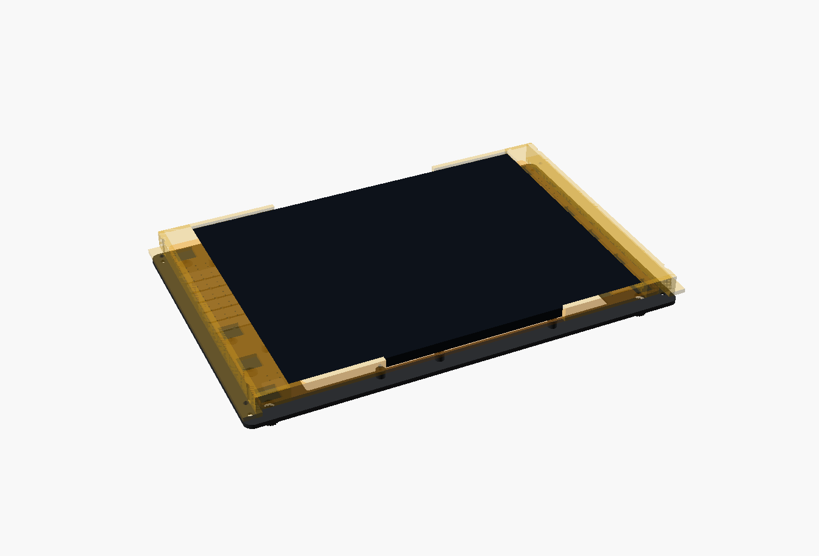
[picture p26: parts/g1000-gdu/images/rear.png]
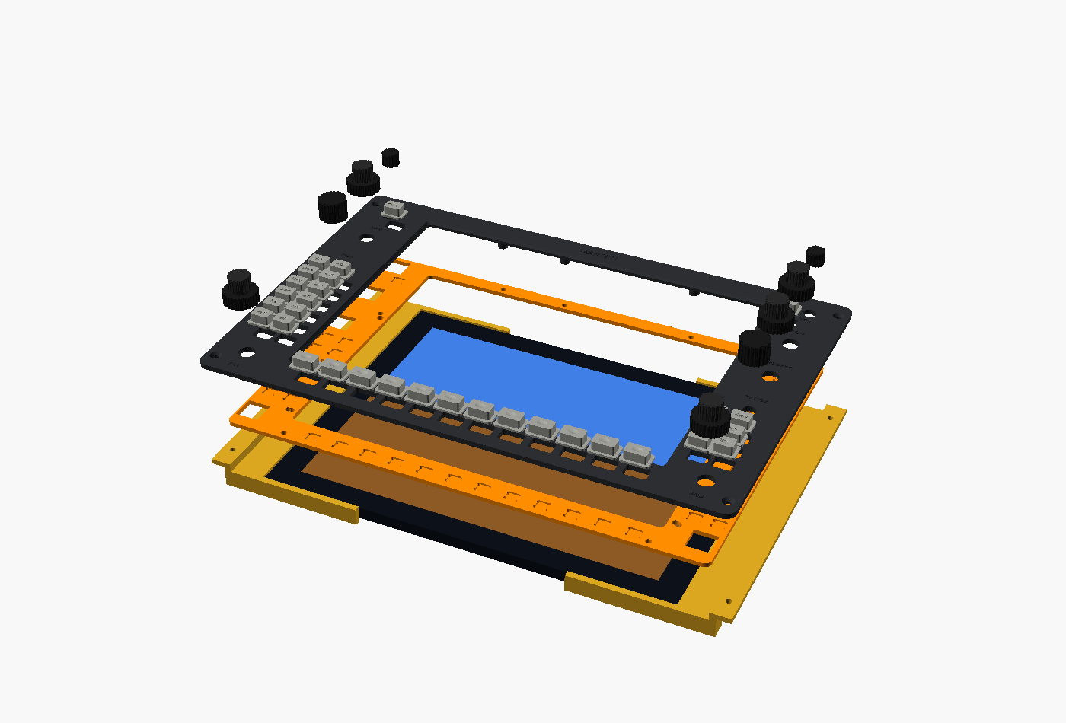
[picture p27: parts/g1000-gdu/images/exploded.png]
|  |  |

## What's on it

- **Keys:** 12 softkeys, NAV and COM frequency flip keys, the 12 GFC 700 autopilot keys (AP FD / HDG ALT / NAV VNV / APR BC / VS UP / FLC DN), and the 6 FMS keys (D→ MENU / FPL PROC / CLR ENT).
- **Knobs:** NAV VOL, NAV (dual), HDG, ALT (dual), COM VOL, COM (dual), CRS/BARO (dual), RANGE and FMS (dual).
- **Screen:** a 10.4" 4:3 1024×768 LCD, the same size and resolution as the real one, showing MSFS's popped-out PFD or MFD.

## How it's built (kept simple)

- **Front plate:** printed face down with engraved labels; fill them with white paint. On a 300 mm+ bed (QIDI Plus4 and similar) print it in one piece: `front` (300 × 196 mm). On a smaller bed, print `front_left` + `front_right`; the seam runs between softkeys 6 and 7, and the 4 corner screws into the panel hold the halves in line.
- **Key caps:** T-shaped. The flange behind the plate keeps them in and presses a standard **6×6×5 mm tactile switch**. Print them flange-down (`caps_sheet`) in dark grey and paint the engraved labels white.
- **Switch plate:** holds the tactile switches in pockets (legs through, solder on the back). It screws to 9 posts on the back of the front plate. Print `switch_plate` in one piece (277 × 186 mm) if it fits. Otherwise print the two halves; they're split at a different place from the front plate, so they bridge that seam.
- **Encoders:** EC11 (single) and ALPS EC11 dual-shaft (e.g. EC11EBB24C03: 6 mm outer, 3.5 mm inner). They mount in the front plate with their nut on the face, and the knob hides the nut.
- **Screen cradle:** two C-shaped halves screwed to the back of the panel (not the bezel), so the bezel comes off without disturbing the screen. The screen sits about 15 mm behind the face, clear of the switch legs; the real G1000 glass is recessed too.

## Parts list (per bezel)

| Qty | Item |
|---|---|
| 1 | Printed front plate and switch plate (each one piece, or left + right halves), 2 cradle halves, caps sheet, knobs sheet |
| 32 | 6×6×5 mm tactile switches (through-hole) |
| 5 | Dual-shaft EC11 encoders (ALPS EC11EBB24C03 or similar) |
| 4 | Single EC11 encoders with push switch, 6 mm D shaft |
| 1 | 10.4" 1024×768 LCD with HDMI driver board |
| 9 | M3 × 8 screws (switch plate to posts) |
| 4 + 4 | M3 × 16 countersunk screws + nuts (bezel to panel) |
| 4 | M3 × 10 screws (cradle to panel back) |
| 1 | Arduino Mega 2560 (MobiFlight), see [`firmware/G1000_WIRING.md`](../../firmware/G1000_WIRING.md) |

## Notes

- The ALPS dual encoders don't have a push switch, so PUSH 1-2, PUSH CRS CTR and PUSH CRSR aren't available. Use dual encoders with a push switch (e.g. Propwash) if you want them; the holes take a 9 mm bushing.
- Settings: `ap_keys` (turn the autopilot keys off), and `lcd_w` / `lcd_h` / `lcd_t` for your screen.
- The key positions were measured from Garmin's published bezel drawing and photos, so they're close but not exact.

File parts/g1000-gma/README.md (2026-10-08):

# GMA 1347 audio panel

The narrow audio panel between the PFD and MFD, at real size (34.3 × 195.6 mm): 21 audio keys, the volume knob, and the red DISPLAY BACKUP button. It's built the same way as the [G1000 bezel](../g1000-gdu): printed face, T-shaped key caps on 6×6 mm tactile switches, and a printed switch plate.

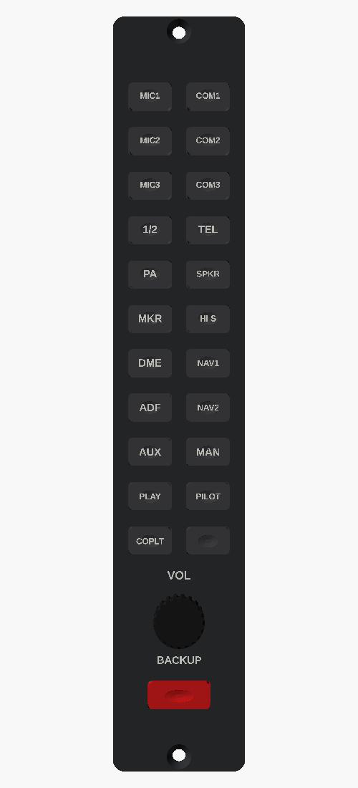
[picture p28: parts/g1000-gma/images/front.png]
GMA 1347


Audio panel working

## Parts list

| Qty | Item |
|---|---|
| 1 each | Printed `front`, `switch_plate`, `caps_sheet` (print the last cap in red: it's DISPLAY BACKUP), `knob` |
| 22 | 6×6×5 mm tactile switches |
| 1 | EC11 encoder with push switch |
| 2 + 2 | M3 × 8 screws (switch plate), M3 × 16 countersunk screws + nuts (to the panel) |

It's wired to board 3 in [`firmware/G1000_WIRING.md`](../../firmware/G1000_WIRING.md). In the sim, mostly COM1/COM2 and the NAV/ADF audio keys do anything.

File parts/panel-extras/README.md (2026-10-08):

# Panel extras

Ignition key working

| Part | What it is |
|---|---|
| `ignition_key` + `ignition_escutcheon` | Key-shaped knob and chrome-look ring on a 1-pole 12-position rotary switch (stop washer set to 5 positions). OFF R L BOTH START is engraved round it on the panel. |
| `knob_alt_static` | Red ALT STATIC AIR knob (look only) |
| `knob_cabin_heat`, `knob_cabin_air` | CABIN HT / CABIN AIR knobs (look only) |
| `knob_fuel_shutoff` | Red FUEL SHUTOFF knob on the pedestal (look only) |
| `knob_stem` + `stem_clip` | Holds any look-only knob in an 8.5 mm panel hole |
| `cb_strip` | A block of circuit-breaker heads; glue two on the lower panel |
| `yoke_boot` | Trim ring with a rubber-boot look round the yoke shaft opening (`yoke_hole_d`, default 60 mm) |

Print the knobs face down; their label is engraved in the face, so fill it with white paint. The key and escutcheon look best in silver.

Extras

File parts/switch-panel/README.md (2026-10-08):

# Switch panels (C-post and lights / dimming)

The two switch plates on the left of the 172S G1000 panel, copied from the real layout:

- **C-post:** STBY BATT (3-position toggle, OFF / ON / TEST) with its test light, MASTER (red ALT | BAT rockers), and AVIONICS (BUS 1 | BUS 2 rockers).
- **Lights / dimming:** 4 dimmer knobs (SW/CB PANELS, STBY IND, PEDESTAL, AVIONICS), and toggles for BEACON, LAND, TAXI, NAV, STROBE, FUEL PUMP, PITOT HEAT and CABIN PWR.

Switch panels working

Switch panels

Off-the-shelf switches clip or screw into the printed plates. The plates are printed face down in grey, with engraved labels you fill with white paint, and each screws over an opening in the dashboard with 4 × M3 countersunk screws.

## Parts list

| Qty | Item | Hole |
|---|---|---|
| 4 | Mini rocker switches, KCD1 style (2 red, 2 grey or white) | 15 × 21 mm (`rocker_hole`) |
| 9 | Mini toggle switches (MTS-102, 6 mm bushing); use an ON-OFF-ON for STBY BATT | 6.4 mm |
| 4 | 10 kΩ linear pots, 16 mm, 6 mm D shaft | 7.4 mm |
| 1 | 5 mm green LED + 220 Ω resistor | 8 mm (holder) |
| 4 | Printed `dimmer_knob` | |
| 8 | M3 × 12 countersunk screws | |

The plate is thinned to 2 mm round the rockers so their clips grip. If yours need a different cut-out, change `rocker_hole`, `toggle_hole_d` or `pot_hole_d`.

They're wired to board 3 in [`firmware/G1000_WIRING.md`](../../firmware/G1000_WIRING.md). With the AY210 base behind the panel its own 13 switches are out of reach, so these take over.

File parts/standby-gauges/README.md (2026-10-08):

# Standby instruments

The standby airspeed, attitude and altimeter that sit below the G1000 screens. Each one is a printed 3-1/8" instrument case with a face you print on paper.

Faces

- **Case:** prints face down in black. A square bezel on the panel face, with a cup behind that goes through an 80 mm panel hole. 4 × M3 screws at the corners.
- **Face:** print [`faces/airspeed.svg`](faces/airspeed.svg), [`attitude.svg`](faces/attitude.svg) and [`altimeter.svg`](faces/altimeter.svg) at **100 %** on photo paper, cut them out, and glue them to the printed `face_disc`. A clear disc cut from a plastic sheet makes the glass.
- **Airspeed markings:** the 172S arcs in knots: white 40–85, green 48–129, yellow 129–163, red line at 163.
- **Static:** these instruments don't move; the screens show the live data. A 2.1" round LCD would fit the case later if you want them live.

To change the faces, run `python3 make_faces.py`, which rewrites the SVGs.

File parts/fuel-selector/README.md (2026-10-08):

# Fuel Selector

The pointer handle on the pedestal floor, over a LEFT / BOTH / RIGHT placard, as in the 172S. For older 172s that have OFF on the selector, set `has_off = true`.

fuel-selector working

| Pointing BOTH | Pointing LEFT | Underneath |
|---|---|---|
|  |  |  |

## How it works (kept simple)

- **Gearing:** the handle shaft carries a 12-tooth gear that turns a 36-tooth gear on a standard **1-pole 12-position rotary switch**. The switch clicks every 30°, so with the 3:1 reduction the handle clicks every 90°: one click per tank position.
- **Stops:** an arm on the handle gear hits two printed stops at LEFT and RIGHT, so the stop washer inside the switch never takes the load. With `has_off = true` the printed stops are removed, so set the switch's own stop washer to 4 positions.

## Parts list

| Qty | Item | Notes |
|---|---|---|
| 1 each | Printed: `handle`, `shaft`, `handle_gear`, `switch_gear`, `housing`, `switch_bracket`, `placard` | [`stl/`](stl) |
| 1 | 1P12T rotary switch (3/8" bushing, 6 mm shaft) | The shaft must reach 20 mm past the mounting face. Cut longer shafts. |
| 2 | M3 × 12 screws | Handle → shaft (from the top), gear → shaft (from below) |
| 2 | M3 × 8 screws | Switch bracket → posts |
| 4 + 4 | M3 × 14 countersunk screws + M3 nuts | Floor-plate mount |

## Printing

No supports are needed. The handle prints flat-side down; print it in white or cream. The placard prints face up; paint the plate black and dry-brush the letters white.

## Assembly

1. Bolt the housing under the floor plate with "FWD" toward the panel.
2. Push the shaft up through the boss (D-flat facing forward). Put the placard and handle on top and screw the handle down.
3. From below, push the handle gear onto the shaft with its arm pointing forward, and screw it on.
4. Turn the handle to BOTH. Fit the switch in the bracket, press the big gear onto the switch shaft so the two gears mesh, and screw the bracket onto the posts. Check that LEFT, BOTH and RIGHT each land on a click.

## Wiring and sim

Wire the switch common to GND. The three switch positions the handle reaches go to pins 3 (LEFT), 4 (BOTH) and 5 (RIGHT), plus pin 6 for OFF if you built it. The Pro Micro sketch in [`/firmware`](../../firmware) holds button 4, 5, 6 or 7 for the selected position.

In MSFS, bind them to the fuel selector left / both (all) / right events. With MobiFlight, use `(>K:FUEL_SELECTOR_LEFT)`, `(>K:FUEL_SELECTOR_ALL)`, `(>K:FUEL_SELECTOR_RIGHT)` and `(>K:FUEL_SELECTOR_OFF)` on press. Some add-on aircraft use their own variables, so check on the ground first.

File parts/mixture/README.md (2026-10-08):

# Mixture

Red ribbed vernier-style knob with the centre lock button, on a hex bushing nut.

mixture working

It uses the same mechanism, parts list and assembly as the throttle; see [`../throttle/README.md`](../throttle/README.md).

| Pushed in (rich) | Pulled out (idle cut-off) | Knob |
|---|---|---|
|  |  |  |

The button is moulded in as part of the knob, so it doesn't lock. You can use a filament change at the button layers to make it black, or paint it. Print the knob back-down.

Wire it to A1 (Y axis) in the Pro Micro sketch and bind it to *Mixture axis* in MSFS.

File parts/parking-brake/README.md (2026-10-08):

# Parking Brake

Modelled on the Cessna 172 parking brake: a black L-shaped lever on a 3/8" shaft that comes out of the lower panel, below the switch row and left of the throttle.

parking-brake working

- **To set it:** pull the handle aft and rotate it 90° so the grip points down.
- **To release it:** rotate it back up. The spring pulls it home.

| Released | Set |
|---|---|
| released | set |

| Behind the panel | Exploded |
|---|---|
| rear | exploded |

## How it works (kept simple)

- **Housing:** a printed tube bolted behind the panel, with an L-shaped slot cut in its wall.
- **Lug:** a small lug on the shaft rides in that slot. The handle can only rotate once it's fully out. At the end of the turn the lug drops into a 3 mm notch, and the spring holds it there.
- **Spring:** compressed when you pull, so it returns the handle when released.
- **Microswitch:** on the rear cap, pressed by the end of the shaft when the handle is in.
- **M3 threaded rod:** runs through the shaft and clamps the handle on, so the printed shaft is always in compression.

## Mounting to the panel

All controls in this repo mount the same way. Four M3 countersunk screws go in from the front of the panel, through the housing flange, and into M3 nuts sitting in hex pockets on the back of the flange.

- **Panel holes:** a 16 mm centre hole plus four 3.4 mm holes on a 28 × 28 mm square, countersunk on the front.
- **Template:** [`panel-template/`](panel-template) has an SVG to print at 100% and a DXF for a laser or CNC.
- **If you print your panel:** the cutouts are already in the files in [`/panel`](../../panel).
- **Escutcheon:** a small domed ring that hides the edge of the hole. Its spigot pushes into the hole; add a drop of glue.

## Parts list

| Qty | Item | Notes |
|---|---|---|
| 1 each | Printed: `housing`, `shaft`, `handle`, `escutcheon`, `rear_cap` | [`stl/`](stl) |
| 1 | Compression spring, OD ≤ 17 mm, ID ≥ 11 mm, ~44 mm long | Must compress below 13 mm. A 1.0 × 14 × 45 mm spring from an assortment works. |
| 1 | M3 threaded rod, ~90 mm | The exact length is printed in OpenSCAD's console |
| 2 | M3 nuts | One in the handle, one in the shaft tail |
| 4 + 4 | M3 × 14 countersunk screws + M3 nuts | Panel mount (6.35 mm panel) |
| 2 | M3 × 8 screws | Rear cap |
| 1 | Microswitch with lever, 20 × 10 × 6.4 mm (KW11 / SS-5GL / V-153) | |
| 2 | M2 × 10 screws + nuts | Microswitch |

## Printing

No supports are needed for any part; each STL is already in its print orientation. Use PLA or PETG at 0.2 mm layers, with 4 walls for the shaft and handle. Print the handle in black.

## Assembly

1. Slide the spring onto the shaft. Drop the shaft into the back of the housing so the nose comes out of the front and the lug enters the slot.
2. Screw on the rear cap and check that the handle pulls, twists and locks. If it binds, sand the slot or raise `clearance`.
3. Mount the microswitch on the cap. The plate has slots so you can slide the switch until it clicks with the handle fully in.
4. Bolt the housing behind the panel with "UP" at the top, then push the escutcheon into the hole from the front.
5. Put an M3 nut in the shaft tail and thread the rod through. Slide the second nut into the slot under the handle, push the handle onto the D-flat with the grip pointing right (brake off), and screw it tight.

## Wiring and sim

Wire the microswitch's **COM** and **NC** terminals to one input. The button is held while the brake is set.

- **With the Pro Micro sketch** in [`/firmware`](../../firmware): use pin 2. You get button 1 (held), plus button 2 (a pulse when the brake is set) and button 3 (a pulse when it's released).
- **In MSFS:** bind "set parking brake" to the press and "release parking brake" to the release. The most reliable way is a MobiFlight input with `1 (>K:PARKING_BRAKE_SET)` on press and `0 (>K:PARKING_BRAKE_SET)` on release.

## Options (OpenSCAD Customizer)

`stowed_side` (which way the grip points when off), `travel`, `grip_len`, `grip_rake`, `panel_thickness` and `clearance`.

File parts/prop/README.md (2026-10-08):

# Prop (constant-speed)

The 172 has a fixed-pitch prop, so the standard 172 doesn't have this control. Build it if you also fly constant-speed aircraft like the 172RG, 182 or Comanche. The knob is blue with a crenellated edge, on a hex bushing nut.

prop working

It uses the same mechanism, parts list and assembly as the throttle; see [`../throttle/README.md`](../throttle/README.md).

| Pushed in (high RPM) | Pulled out | Knob |
|---|---|---|
|  |  |  |

Wire it to A2 (Z axis) in the Pro Micro sketch, set `HAS_PROP = true` there, and bind it to *Propeller axis* in MSFS. To place it between the throttle and mixture on the printed panel, set `has_prop = true` in [`/panel`](../../panel).

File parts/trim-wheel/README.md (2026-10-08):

# Elevator Trim Wheel

The black ridged trim wheel from the 172's centre pedestal. It sticks out of a slot in the pedestal face, with a NOSE DN / T.O. / NOSE UP placard beside it. Roll the top forward for nose down, like the real one.

trim-wheel working

| Front | Behind the panel | Wheel |
|---|---|---|
|  |  |  |

## How it works (kept simple)

- **Bearings:** the wheel spins on an M8 bolt in two 608 skateboard bearings. Printed bosses on the side walls press on the inner races to keep it centred.
- **Sensor:** a gear moulded onto the side of the wheel (48 teeth) drives a 16-tooth gear on an EC11 rotary encoder. That's 3:1, so each click of the encoder is a small trim step. The real indicator needle isn't modelled; the placard shows the marks.

## Parts list

| Qty | Item | Notes |
|---|---|---|
| 1 each | Printed: `wheel`, `housing`, `encoder_gear`, `placard` | [`stl/`](stl) |
| 2 | 608 bearings (8 × 22 × 7 mm) | |
| 1 | M8 × 55 bolt + nyloc nut | Don't over-tighten: just snug on the bearing inner races |
| 1 | EC11 rotary encoder, 6 mm D shaft (20 detents) | **Cut its shaft to 12 mm** from the mounting face |
| 4 + 4 | M3 × 14 countersunk screws + M3 nuts | Panel mount |

## Printing

- **wheel:** prints flat with the gear side up. Print it in black.
- **housing:** prints with the front plate down. The walls stand up; the small horizontal bosses print fine without supports.
- **placard:** paint the plate black and dry-brush the raised letters white, or use a filament change.

## Assembly

1. Press the bearings into both sides of the wheel.
2. Mount the encoder on the outside of the gear-side wall: its bushing goes through the 7 mm hole, with the nut on the inside. Push the encoder gear onto the shaft.
3. Set the wheel between the walls and push the M8 bolt through. Check that the gears mesh and the wheel spins freely, then fit the nut.
4. Bolt the housing behind the pedestal face. The panel slot is 26 × 104 mm, with screws at ±27 / ±55 mm. Glue the placard beside the slot on the pilot's left.

## Wiring and sim

Encoder A → pin 7, B → pin 8, middle pin → GND, using the Pro Micro sketch in [`/firmware`](../../firmware).

Each click sends button 8 (nose down) or button 9 (nose up). Bind these to *Elevator trim down* and *Elevator trim up* in MSFS. If they come out backwards, set `REVERSE_TRIM = true` in the sketch.

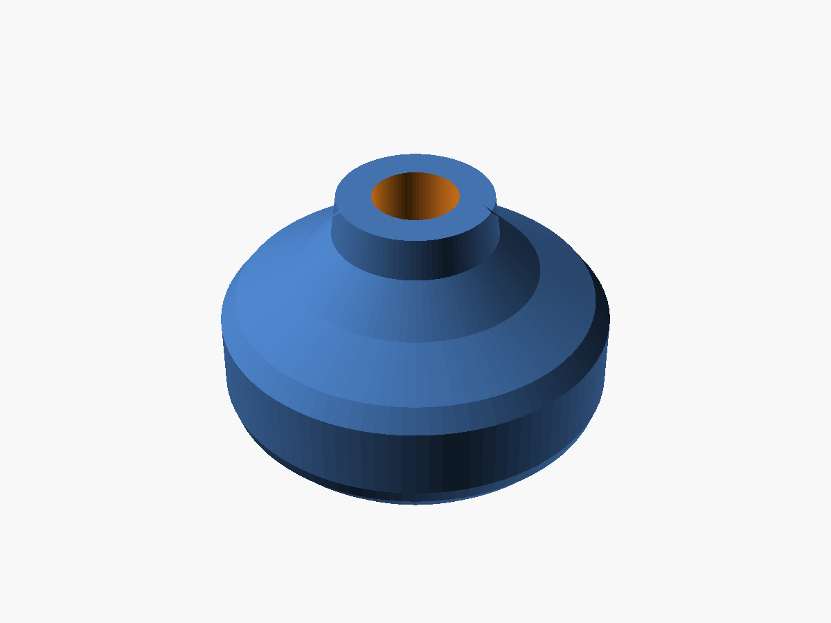
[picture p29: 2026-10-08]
parts/throttle/images/knob.png

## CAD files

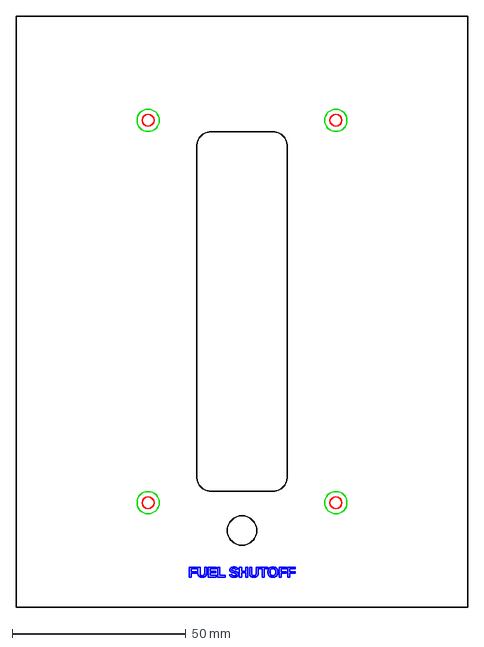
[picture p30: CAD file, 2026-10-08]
panel/dashboard/cnc/pedestal_face.dxf
130.0 x 170.0 mm

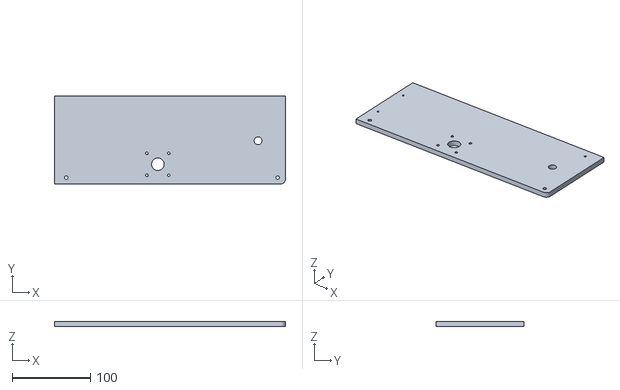
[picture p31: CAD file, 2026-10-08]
panel/dashboard/stl/tile_L1.stl
295.0 x 112.0 x 6.35

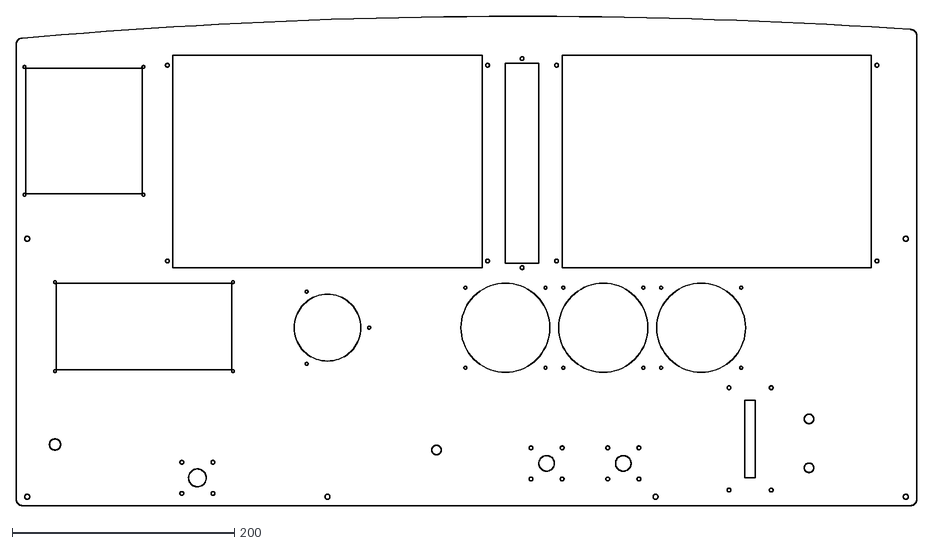
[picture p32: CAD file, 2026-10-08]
panel/dashboard/templates/dashboard_panel.dxf
810.0 x 440.0

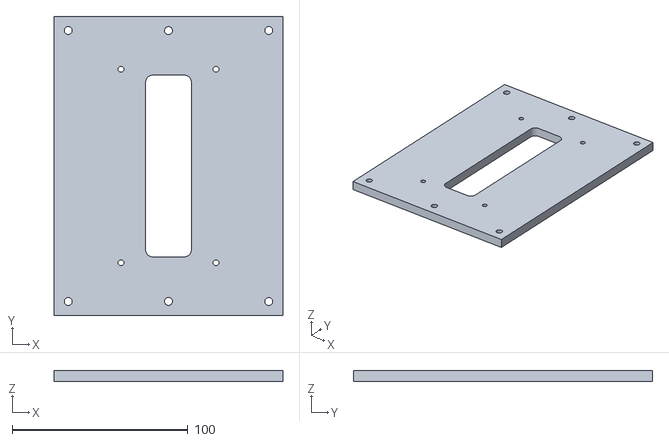
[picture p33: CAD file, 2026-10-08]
panel/stl/pedestal.stl
130.0 x 170.0 x 6.35

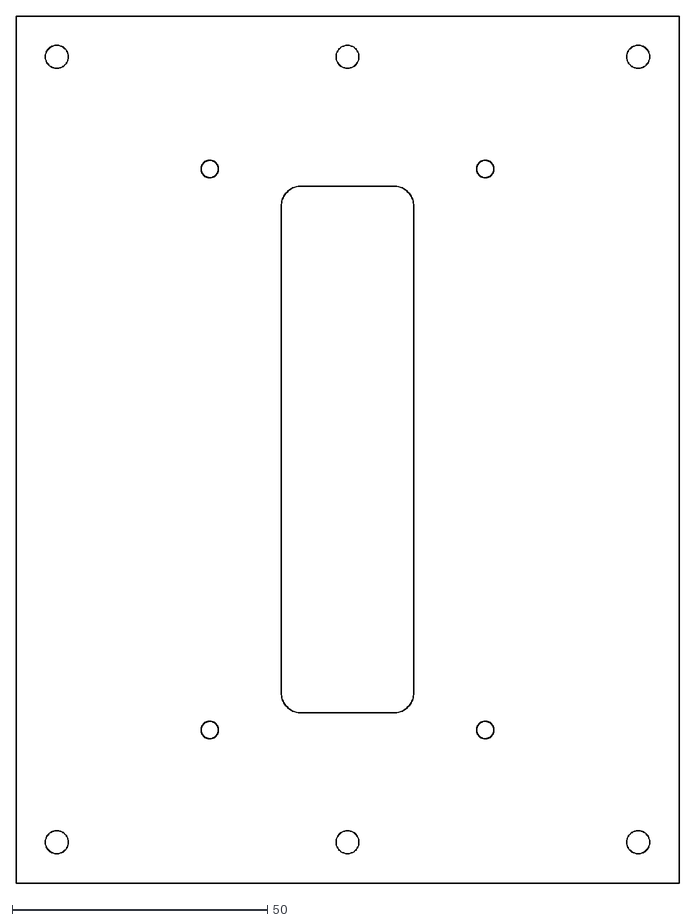
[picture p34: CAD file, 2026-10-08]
panel/templates/pedestal_panel.dxf
130.0 x 170.0

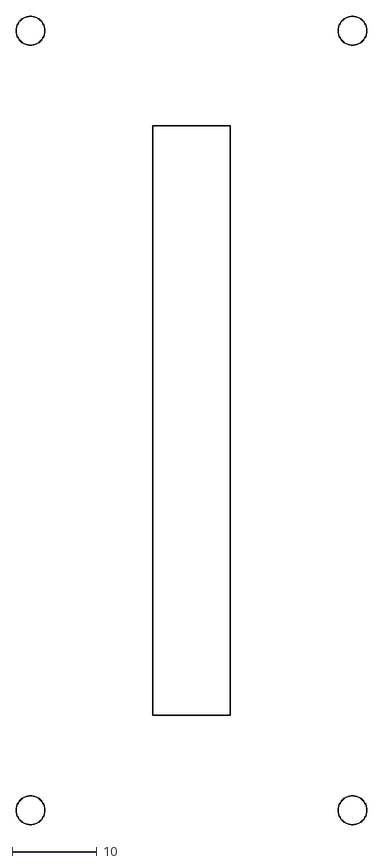
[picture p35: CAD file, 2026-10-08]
parts/flap-lever/panel-template/flap_lever_cutout.dxf
41.4 x 95.4

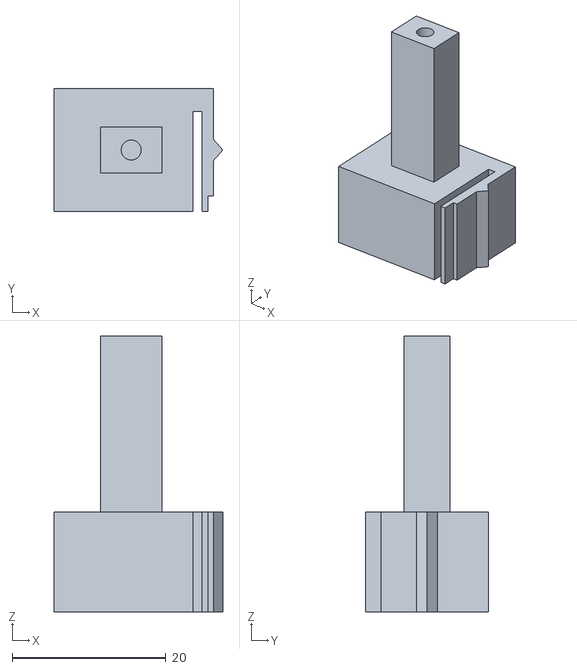
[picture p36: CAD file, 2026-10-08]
parts/flap-lever/stl/carriage.stl
21.9 x 16.0 x 35.8

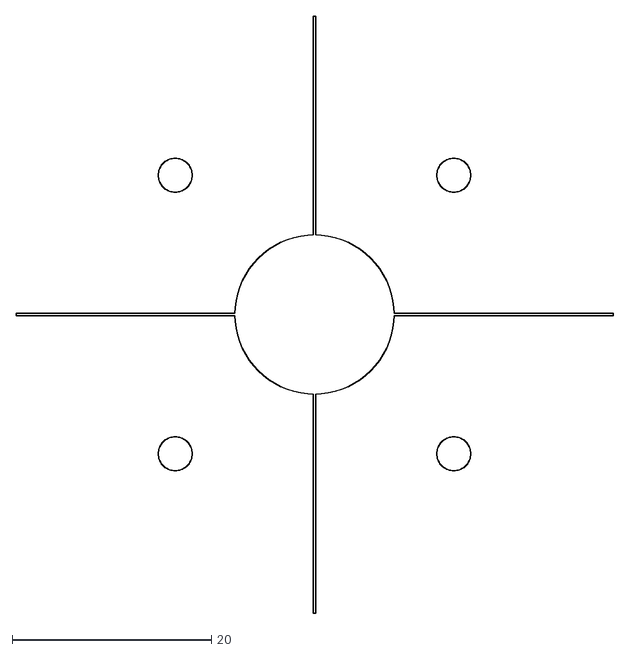
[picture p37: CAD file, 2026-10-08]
parts/fuel-selector/panel-template/fuel_selector_cutout.dxf
60.0 x 60.0

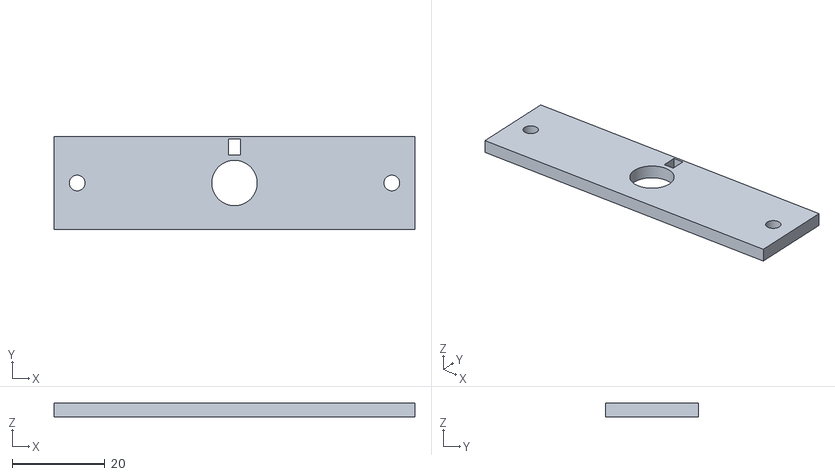
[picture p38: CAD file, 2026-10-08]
parts/fuel-selector/stl/switch_bracket.stl
78.0 x 20.0 x 3.00

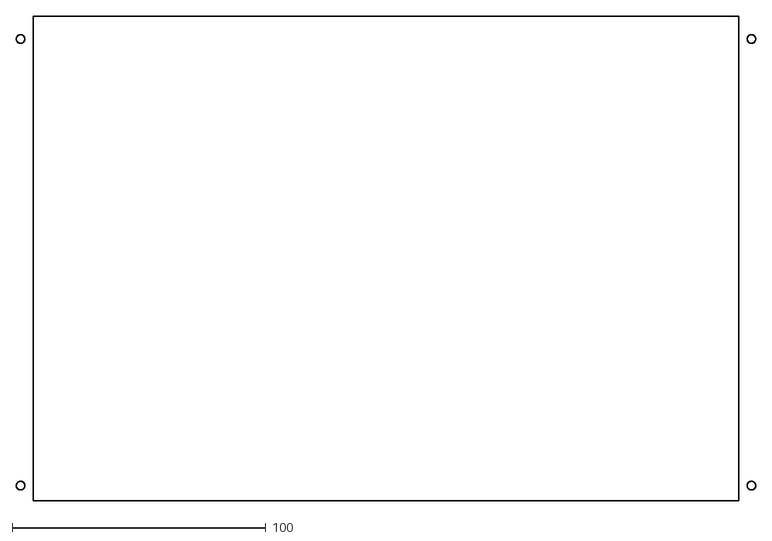
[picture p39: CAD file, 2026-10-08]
parts/g1000-gdu/panel-template/g1000_gdu_cutout.dxf
291.4 x 191.0

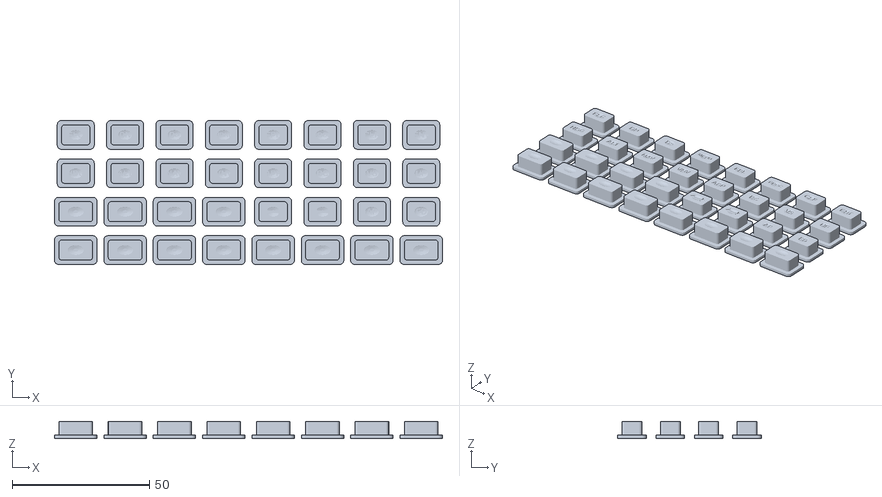
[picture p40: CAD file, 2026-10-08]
parts/g1000-gdu/stl/caps_sheet.stl
141.5 x 52.5 x 6.20

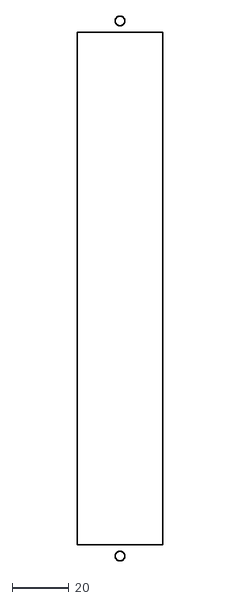
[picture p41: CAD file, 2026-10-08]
parts/g1000-gma/panel-template/g1000_gma_cutout.dxf
30.0 x 191.4

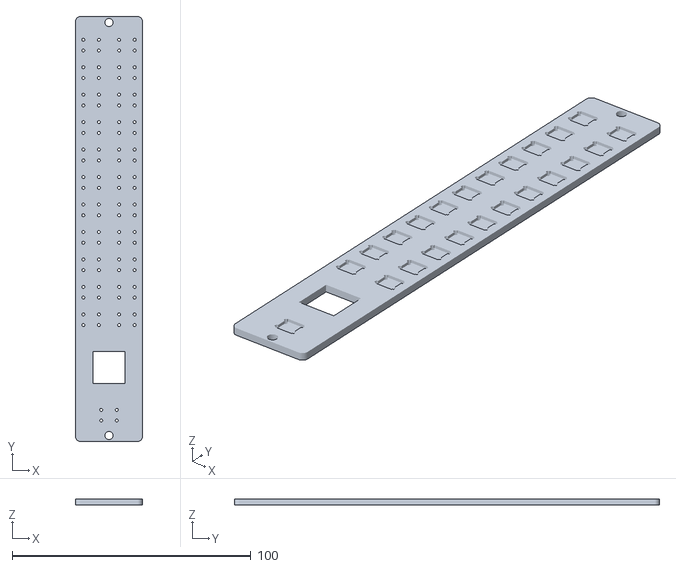
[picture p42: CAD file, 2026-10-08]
parts/g1000-gma/stl/switch_plate.stl
28.0 x 178.0 x 2.50

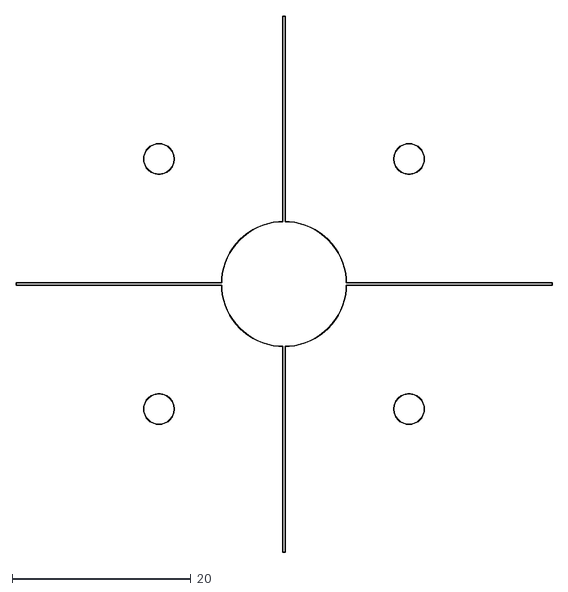
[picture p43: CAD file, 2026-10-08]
parts/mixture/panel-template/mixture_cutout.dxf
60.0 x 60.0

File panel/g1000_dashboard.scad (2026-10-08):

// Cessna 172S G1000 DASHBOARD for the home sim - shortened to about 32" (810 mm).
//
// Everything from the left switch panel to just past the MFD, at real scale:
//   upper (grey):  C-post switch panel, PFD, GMA 1347 audio panel, MFD,
//                  dimming/lights panel, yoke shaft opening (Moza AY210),
//                  standby airspeed / attitude / altimeter
//   lower (black): ignition key, circuit breakers (look only), parking brake,
//                  ALT STATIC AIR, throttle, mixture, flap lever, cabin heat/air
//   pedestal:      elevator trim wheel, fuel shutoff, floor with fuel selector
//   glareshield over the top
//
// The panel is printed as tiles that butt together (grey upper tiles, black
// lower tiles). The modules (bezels, switch plates, instruments) overlap the
// seams and tie the tiles together; splice strips on the back do the rest.
// Print tiles FRONT FACE DOWN.
//
// Layout numbers below: x = mm to the pilot's RIGHT of the pilot's centre line
// (the PFD and yoke), y = mm up from the bottom edge of the panel.
//
// Render:  openscad -D 'part="tile_U1"' -o tile_U1.stl g1000_dashboard.scad

include <../common/sim_common.scad>
use <../parts/parking-brake/parking_brake.scad>
use <../parts/throttle/throttle.scad>
use <../parts/mixture/mixture.scad>
use <../parts/trim-wheel/trim_wheel.scad>
use <../parts/fuel-selector/fuel_selector.scad>
use <../parts/g1000-gdu/gdu1040.scad>
use <../parts/g1000-gma/gma1347.scad>
use <../parts/switch-panel/switch_panel.scad>
use <../parts/standby-gauges/standby_gauges.scad>
use <../parts/panel-extras/panel_extras.scad>
use <../parts/flap-lever/flap_lever.scad>

/* [What to show] */
part = "preview"; // [preview, preview_rear, layout_map, tile_L1, tile_L2, tile_L3, tile_L4, tile_M1, tile_M2, tile_M3, tile_M4, tile_U1, tile_U2, tile_U3, tile_U4, splice, splice_small, glareshield_1, glareshield_2, glareshield_3, glareshield_4, pedestal_face, pedestal_floor, panel_2d, cnc_lower_1, cnc_lower_2, cnc_upper_1, cnc_upper_2, cnc_pedestal_face, cnc_pedestal_floor, cnc_splice, cnc_splice_small, keepout_2d, outline_2d, seam_info]

/* [Panel size] */
x_left = -280;
x_right = 530;
// Panel top edge is an arch: highest at the aircraft centre line (between PFD and MFD)
top_centre = 440;
top_side_drop = 20;
// Height of the black lower panel
lower_h = 112;
// Height where the grey upper panel is split into two rows of tiles
mid_split = 260;

/* [Upper panel] */
pfd_pos = [0, 308];
gma_pos = [175, 308];
mfd_pos = [350, 308];
cpost_pos = [-219, 337];
lights_pos = [-165, 161];
gauge_asi = [160, 160];
gauge_att = [248, 160];
gauge_alt = [336, 160];

/* [Yoke (Moza AY210)] */
yoke_pos = [0, 160];
// Distance from the panel back to the front of the AY210 base (keep things behind the panel shallower than this)
moza_front = 110;
// Height of the yoke shaft above the bottom of the AY210 base (measure yours)
moza_shaft_h = 150;

/* [Lower panel] */
ignition_pos = [-245, 55];
cb1_pos = [-175, 75];
cb2_pos = [-35, 75];
brake_pos = [-117, 25];
alt_static_pos = [98, 50];
throttle_pos = [197, 38];
mixture_pos = [266, 38];
flap_pos = [380, 60];
cabin_heat_pos = [433, 78];
cabin_air_pos = [433, 34];

/* [Pedestal] */
pedestal_x = 231;
pedestal_w = 130;
pedestal_h = 170;
floor_d = 150;

/* [Printing] */
// Print bed size (mm). 305 = QIDI Plus4. Each row is split into tiles no wider than this.
bed = 305;
// Tile seams (x positions) for each row: lower (black), middle and upper (grey).
// Splice plates on the back join the tiles: run scripts/place_splices.py after
// changing the seams or moving things, and it finds room for them (panel/splices.scad).
lower_splits = [15, 310];
mid_splits = [-58, 240];
upper_splits = [-10, 250];
// Glareshield joints (x). Offset from the upper seams so each glareshield piece screws
// into the tiles on both sides of a seam and ties the top edge together. [] = halfway along each upper tile.
glareshield_splits = [];

/* [CNC router] */
// Cutting the panel from 1/4" sheet on a CNC router instead of printing it:
// the lower (black) and upper (grey) panels are each cut in 2 pieces. Lower split at this x:
cnc_lower_split = 15;
// Upper split: [x below the jog, x above it, jog height y]. The default is a straight seam
// through the attitude gauge and the MFD: both bezels screw to both pieces and tie them.
cnc_upper_split = [248, 248, 207];
// Holes narrower than this are drilled instead of routed (mm)
cnc_drill_max = 6;
// Which layer to write for a cnc_* part: "cut" (outline + openings, routed through),
// "drill" (small through holes), "engrave" (labels, 0.6 mm deep), "countersink"
// (M3 head circles, front), "back" (blind pilot holes, mirrored for drilling from the back).
// scripts/make_cnc.py writes them all into one layered DXF / SVG per piece.
cnc_layer = "cut"; // [cut, drill, engrave, countersink, back]

/* [Hidden] */
t = panel_thickness;
// Splice plates, written by scripts/place_splices.py: [x, y, kind] for the printed tiles
// (splices) and the CNC pieces (cnc_splices). kind: "V" 34 x 70 across a vertical seam,
// "H" 70 x 34 across a horizontal joint, "v" / "h" small 2-screw plates for tight spots.
include <splices.scad>
function splice_size(k) = k == "V" ? [34, 70] : k == "H" ? [70, 34] : k == "v" ? [40, 22] : [22, 40];
function splice_holes(k) = k == "V" ? [[-10, -25], [10, -25], [-10, 25], [10, 25]]
                         : k == "H" ? [[-25, -10], [-25, 10], [25, -10], [25, 10]]
                         : k == "v" ? [[-12, 0], [12, 0]] : [[0, -12], [0, 12]];
module splice_pilots_2d(list) for (c = list, h = splice_holes(c[2])) translate([c[0], c[1]] + h) circle(d = m3_pilot_d);
splice_t = 4;   // printed splice thickness: M3 x 8 screws (4 mm into the panel's blind holes)
aircraft_cl = gma_pos[0];
function top_y(x) = top_centre - top_side_drop * pow((x - aircraft_cl) / (aircraft_cl - x_left), 2);
function ax(p) = [-p[0], p[1]];                 // layout -> model x (pilot's right = -x)
frame_hole_d = 4.5;

// ------------------------------------------------------------------ panel outline (front view)
module outline_2d() {
    n = 40;
    pts = concat([[x_left, 0], [x_right, 0]],
                 [for (i = [0 : n]) let(x = x_right - (x_right - x_left) * i / n) [x, top_y(x)]]);
    offset(r = 6) offset(delta = -6) polygon(pts);
}

// All cut-outs, front view
module holes_2d() {
    module at(p) translate(p) children();
    at(pfd_pos) gdu_cutout_2d();
    at(mfd_pos) gdu_cutout_2d();
    at(gma_pos) gma_cutout_2d();
    at(cpost_pos) upper_cutout();
    at(lights_pos) lower_cutout();
    for (g = [gauge_asi, gauge_att, gauge_alt]) at(g) gauge_cutout_2d();
    at(yoke_pos) { circle(d = 60); yoke_boot_screw_holes_2d(); }
    at(ignition_pos) circle(d = 10);
    for (p = [alt_static_pos, cabin_heat_pos, cabin_air_pos]) at(p) circle(d = 8.5);
    at(brake_pos) parking_brake_panel_cutout();
    at(throttle_pos) throttle_panel_cutout();
    at(mixture_pos) mixture_panel_cutout();
    at(flap_pos) flap_cutout_2d();
    // frame screws along the bottom and the sides
    for (x = concat([x_left + 10], [for (s = lower_splits) s - 15], [x_right - 10])) translate([x, 8]) circle(d = frame_hole_d);
    for (x = [x_left + 10, x_right - 10]) translate([x, mid_split - 20]) circle(d = frame_hole_d);
}

// Engraving on the panel face, front view (THROTTLE, MIXTURE, FLAP scale, key positions ...)
module engrave_2d() {
    f = "Liberation Sans:style=Bold";
    module lab(p, txt, dy = -27, s = 3.2) translate(p + [0, dy]) text(txt, size = s, font = f, halign = "center", valign = "center");
    lab(throttle_pos, "THROTTLE", -30);
    lab(mixture_pos, "MIXTURE", -30);
    lab(alt_static_pos, "ALT STATIC AIR", -16, 2.6);
    lab(cabin_heat_pos, "CABIN HT", 17, 2.6);
    lab(cabin_air_pos, "CABIN AIR", -17, 2.6);
    lab(brake_pos, "PARK BRAKE", -18, 2.6);
    translate(flap_pos) flap_scale_2d_();
    translate(ignition_pos) ignition_labels_2d();
}

// Back-side blind pilot holes (front view): G1000 screen cradles + splice strips
module back_pilots_2d() {
    for (p = [pfd_pos, mfd_pos]) translate(p) gdu_cradle_holes_2d();
    splice_pilots_2d(splices);
    for (i = [0 : len(GS_edges) - 2], x = gs_screws(i)) translate([x, top_y(x) - 18]) circle(d = m3_pilot_d);
}
// Countersinks (front view positions + kind)
cs_list = concat([for (p = [brake_pos, throttle_pos, mixture_pos]) [p, "std"]], [[flap_pos, "flap"]]);
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

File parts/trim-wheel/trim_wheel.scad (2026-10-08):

// Cessna 172-style ELEVATOR TRIM WHEEL for a home sim pedestal
//
// Outside: a black wheel with cross ridges sticking out of a slot in the
// pedestal face, with a NOSE DN / TAKEOFF / NOSE UP placard beside it.
// Roll it forward (top away from you) for nose down, like the real one.
//
// Inside (kept simple): the wheel spins on an M8 bolt in two 608 skateboard
// bearings. A gear moulded onto the side of the wheel turns a small gear on an
// EC11 rotary encoder (3:1, so you get fine trim steps).
//
// Render one part:  openscad -D 'part="wheel"' -o wheel.stl trim_wheel.scad

include <../../common/sim_common.scad>

/* [What to show] */
part = "assembly"; // [assembly, exploded, wheel, housing, encoder_gear, placard, panel_test_plate, panel_cutout]

/* [Wheel] */
wheel_d = 110;
wheel_w = 22;
// How far the wheel sticks out in front of the panel face
expose = 18;
ridges = 40;

/* [Hidden] */
R        = wheel_d / 2;
gear_m   = 1;
wheel_gear_z = 48;   // must stay behind the panel: tip radius < axle depth
enc_gear_z   = 16;   // 3:1
gear_t   = 5;
backlash = 0.25;
centre_dist = gear_m * (wheel_gear_z + enc_gear_z) / 2 + backlash;
z_c      = R - expose - panel_thickness;     // axle, behind the panel back face (z = 0)
bearing_d = 22; bearing_w = 7; bearing_bore = 8;
x_wheel  = wheel_w / 2;                       // wheel faces at +/- x_wheel
x_gear1  = x_wheel + gear_t;                  // outer face of the wheel gear
wall_t   = 4;
x_wall_p = x_gear1 + 4;                       // +x wall inner face (room for the encoder bushing + nut)
x_wall_n = -(x_wheel + 1.5);                  // -x wall inner face
y_half   = R + 4;                             // housing half height
plate_t  = 5;
// the wheel is widest where it crosses the back of the housing plate, so size the slot there
slot_len = 2 * sqrt(R * R - (z_c - 5) * (z_c - 5)) + 6;
slot_w   = wheel_w + 4;
enc_pos  = [0, z_c + centre_dist];            // (y, z) of the encoder shaft
enc_hole = 7.2;                               // EC11 M7 bushing
flange_x1 = x_wall_p + wall_t + 8; flange_x0 = -flange_x1;
hole_x   = flange_x1 - 5; hole_y = y_half - 4; // flange screw positions

// ------------------------------------------------------------------ wheel
// Modelled with its axle along +z for printing (gear side up); assembly turns it.

module wheel_local() {
    difference() {
        union() {
            // rim with cross ridges, like the real wheel's tread
            cylinder(r = R - 1.5, h = wheel_w, $fn = 160);
            for (i = [0 : ridges - 1]) rotate([0, 0, i * 360 / ridges])
                translate([R - 2, -1.4, 0]) hull() {
                    cube([0.1, 2.8, wheel_w]);
                    translate([1.9, 0.5, 0.8]) cube([0.1, 1.8, wheel_w - 1.6]);
                }
            // gear on the top face
            translate([0, 0, wheel_w - 0.01]) spur_gear(gear_m, wheel_gear_z, gear_t);
        }
        // bearing seats both sides + through bore
        translate([0, 0, -0.01]) cylinder(d = bearing_d + 0.15, h = bearing_w);
        translate([0, 0, wheel_w + gear_t - bearing_w - gear_t + 0.01]) cylinder(d = bearing_d + 0.15, h = bearing_w + gear_t);
        cylinder(d = bearing_d - 3, h = 100, center = true);
        // dished faces (the real wheel is thinner in the middle) - only on the plain side
        translate([0, 0, -0.01]) difference() {
            cylinder(r = R - 8, h = 2);
            cylinder(r = 17, h = 2);
        }
        // clear the inside of the gear ring down to the bearing so the boss can reach it
        translate([0, 0, wheel_w]) cylinder(r = 15, h = gear_t + 1);
    }
}

// in assembly coords: axle along x, gear on +x side
module wheel() {
    translate([-x_wheel, 0, z_c]) rotate([0, 90, 0]) rotate([0, 0, 0]) wheel_local();
}

// ------------------------------------------------------------------ encoder gear
module encoder_gear() {
    difference() {
        union() {
            spur_gear(gear_m, enc_gear_z, gear_t);
        }
        // 6 mm D shaft (EC11)
        translate([0, 0, -1]) linear_extrude(gear_t + 6) difference() {
            circle(d = 6.15);
            translate([-5, 1.6]) square([10, 5]);   // 4.5 mm across the flat
        }
    }
}

// ------------------------------------------------------------------ housing
// Front plate (behind the panel) + two side walls. Prints front plate down.

module wall_profile(enc) {   // 2D in (y, z)
    hull() {
        translate([-y_half, 0]) square([2 * y_half, 1]);
        translate([0, z_c]) circle(r = 15);
        if (enc) translate(enc_pos) circle(r = 11);
    }
}

module housing() {
    difference() {
        union() {
            // front plate
            translate([flange_x0, -y_half, 0]) cube([flange_x1 - flange_x0, 2 * y_half, plate_t]);
            // side walls
            // 2D (y, z) profile -> wall of thickness wall_t along x
            translate([x_wall_p, 0, 0]) multmatrix([[0, 0, 1, 0], [1, 0, 0, 0], [0, 1, 0, 0]]) linear_extrude(wall_t) wall_profile(true);
            translate([x_wall_n - wall_t, 0, 0]) multmatrix([[0, 0, 1, 0], [1, 0, 0, 0], [0, 1, 0, 0]]) linear_extrude(wall_t) wall_profile(false);
            // bosses that press on the bearing inner races (centre the wheel)
            translate([x_wall_n - 0.01, 0, z_c]) rotate([0, 90, 0]) cylinder(d = 12, h = (-x_wheel - 0.3) - x_wall_n);
            translate([x_wheel + 0.3, 0, z_c]) rotate([0, 90, 0]) cylinder(d = 12, h = x_wall_p - x_wheel - 0.3 + 0.01);
        }
        // wheel slot
        translate([-slot_w/2, -slot_len/2, -1]) cube([slot_w, slot_len, plate_t + 2]);
        // axle
        translate([x_wall_n - wall_t - 1, 0, z_c]) rotate([0, 90, 0]) cylinder(d = 8.4, h = 100);
        // encoder
        translate([x_wall_p - 1, enc_pos[0], enc_pos[1]]) rotate([0, 90, 0]) cylinder(d = enc_hole, h = wall_t + 2);
        // flange screws + nuts
        for (x = [-hole_x, hole_x], y = [-hole_y, hole_y]) translate([x, y, 0]) {
            translate([0, 0, -1]) cylinder(d = m3_clear_d, h = plate_t + 2);
            translate([0, 0, plate_t - m3_nut_t - 0.6]) m3_nut_pocket(m3_nut_t + 1);
        }
    }
}

// ------------------------------------------------------------------ placard
// Sits on the panel face to the left of the wheel slot. Raised letters: paint
// the plate black and dry-brush the letters white.

module placard() {
    w = 24; h = slot_len;
    translate([0, 0, 0]) {
        linear_extrude(1.2) rounded_rect([w, h], 2);
        translate([0, 0, 1.2]) linear_extrude(0.6) {
            translate([0, h/2 - 6]) text("NOSE", size = 3.4, halign = "center", valign = "center", font = "Liberation Sans:style=Bold");
            translate([0, h/2 - 11]) text("DN", size = 3.4, halign = "center", valign = "center", font = "Liberation Sans:style=Bold");
            translate([0, h/2 - 17]) polygon([[-3, -2], [3, -2], [0, 2]]);
            // takeoff mark slightly nose-up of centre, like the real indicator
            translate([0, -6]) {
                translate([-w/2 + 1.5, -0.4]) square([5, 0.8]);
                text("T.O.", size = 3.4, halign = "center", valign = "center", font = "Liberation Sans:style=Bold");
            }
            translate([0, -h/2 + 17]) polygon([[-3, 2], [3, 2], [0, -2]]);
            translate([0, -h/2 + 11]) text("NOSE", size = 3.4, halign = "center", valign = "center", font = "Liberation Sans:style=Bold");
            translate([0, -h/2 + 6]) text("UP", size = 3.4, halign = "center", valign = "center", font = "Liberation Sans:style=Bold");
        }
    }
}

// ------------------------------------------------------------------ panel bits

module panel_cutout() {
    translate([0, 0]) rounded_rect([slot_w, slot_len], 4);
    for (x = [-hole_x, hole_x], y = [-hole_y, hole_y]) translate([x, y]) circle(d = m3_clear_d);
    // placard outline (left of the wheel as the pilot sees it)
    translate([slot_w/2 + 18, 0]) difference() { rounded_rect([24.6, slot_len + 0.6], 2); rounded_rect([24, slot_len], 2); }
}

module panel_test_plate() {
    difference() {
        linear_extrude(panel_thickness) difference() {
            rounded_rect([flange_x1 - flange_x0 + 50, 2 * y_half + 20], 4);
            rounded_rect([slot_w, slot_len], 4);
            for (x = [-hole_x, hole_x], y = [-hole_y, hole_y]) translate([x, y]) circle(d = m3_clear_d);
        }
        for (x = [-hole_x, hole_x], y = [-hole_y, hole_y]) translate([x, y, -0.01])
            cylinder(d1 = m3_head_d + 0.4, d2 = m3_clear_d, h = (m3_head_d + 0.4 - m3_clear_d) / 2);
    }
}

// ------------------------------------------------------------------ views

module panel_slab() {
    color([0.30, 0.31, 0.33], ghost_a(0.55)) translate([0, 0, -panel_thickness]) linear_extrude(panel_thickness) difference() {
        translate([-90, -85]) square([180, 170]);
        rounded_rect([slot_w, slot_len], 4);
    }
}
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

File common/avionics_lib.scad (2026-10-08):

// Shared building blocks for the avionics bezels (G1000 PFD/MFD, audio panel).
//
// Bezels are modelled FACE-UP, as you see them from the seat: x to the right,
// y up, the face at z = 0 and everything behind it at negative z.
//
//   z 0 .. -face_t           printed front plate (key holes, knob holes, labels)
//   key caps                 T-shaped: the face part pokes 2 mm out of the
//                            front plate, the flange behind it keeps it in and
//                            presses the switch plunger directly (prints flange-down)
//   z -sw_z ..               printed switch plate holding 6 x 6 mm tactile
//                            switches (the common 6x6x5 mm through-hole kind)
//   encoders                 EC11 single and EC11 dual-shaft, bushing through
//                            the front plate, nut on the face (the knob hides it)
//
// Include after sim_common.scad.

face_t      = 3;      // front plate thickness
cap_out     = 2;      // how far keys stand proud of the face
cap_flange  = 1.2;    // key-cap flange thickness
cap_stem    = 0.2;    // free play between the cap flange and the switch plunger
tact_body   = 3.5;    // 6x6 switch body height
tact_plunge = 1.5;    // plunger above the body
pocket_d    = 1.0;    // switch body sits this deep in its pocket
sw_gap      = cap_flange + cap_stem + tact_plunge + tact_body - pocket_d;  // face back -> switch plate front
sw_z        = face_t + sw_gap;   // switch plate front face
sw_t        = 2.5;    // switch plate thickness
post_d      = 6;      // standoff posts on the back of the front plate

enc1_bush_d = 7.3;    // EC11 single: M7 bushing
enc2_bush_d = 9.3;    // EC11 dual-shaft (ALPS EC11EBB24C03 etc.); fine for M7 with a washer too
enc_body    = 13.5;   // clearance for the encoder body in the switch plate

label_font  = "Liberation Sans:style=Bold";

// ---------- front plate features (subtract from the plate; face at z = 0)

module key_hole(w, h) {
    translate([0, 0, -face_t - 1]) linear_extrude(face_t + 2) rounded_rect([w + 0.4, h + 0.4], 1.2);
}
module enc_hole(dual = false) {
    translate([0, 0, -face_t - 1]) cylinder(d = dual ? enc2_bush_d : enc1_bush_d, h = face_t + 2);
}
// Recessed label in the face. Fill with white paint.
module face_label(txt, size = 2.6, halign = "center") {
    translate([0, 0, -0.6]) linear_extrude(1)
        text(txt, size = size, font = label_font, halign = halign, valign = "center");
}
// Two-headed arrow (the frequency "flip" key symbol), 2D
module flip_arrow(w = 7, h = 3) {
    union() {
        translate([-w/2 + 1.5, -0.4]) square([w - 3, 0.8]);
        for (s = [-1, 1]) translate([s * (w/2 - 1.5), 0]) polygon([[0, h/2], [s * 1.6, 0], [0, -h/2]]);
    }
}

// Standoff posts on the back of the front plate (add to the plate)
module face_post(h = sw_gap) {
    difference() {
        translate([0, 0, -face_t - h]) cylinder(d = post_d, h = h + 0.01);
        translate([0, 0, -face_t - h - 1]) cylinder(d = m3_pilot_d, h = h);
    }
}

// ---------- switch plate features (switch plate front face at z = -sw_z, plate below it)

// Pocket + leg holes for a 6x6 tactile switch, centred on the key.
module tact_pocket() {
    translate([-3.2, -3.2, -sw_z - pocket_d]) cube([6.4, 6.4, pocket_d + 0.01]);  // locate the body
    for (x = [-3.25, 3.25], y = [-2.25, 2.25]) translate([x, y, -sw_z - sw_t - 1]) cylinder(d = 1.3, h = sw_t + 2, $fn = 12);
}
module enc_clear() {
    translate([-enc_body/2, -enc_body/2, -sw_z - sw_t - 1]) cube([enc_body, enc_body, sw_t + 2]);
}
// Key-cap label geometry, at a cap's top face (for render paint)
module cap_label_geom(w, txt, tsize = 2.2, arrow = false) {
    translate([0, 0, -0.6]) linear_extrude(1) {
        if (len(txt) > 0) text(txt, size = tsize, font = label_font, halign = "center", valign = "center");
        if (arrow) flip_arrow(min(w - 3, 7), 3);
    }
}

// Place a key cap (modelled flange-down) in its hole
module cap_in_place() { translate([0, 0, -face_t - cap_flange]) children(); }

// ---------- key caps (printed flange-down, label on top)

// w x h = visible key size. Label is engraved into the key face.
module key_cap(w, h, txt = "", tsize = 2.2, arrow = false) {
    difference() {
        union() {
            linear_extrude(cap_flange) rounded_rect([w + 3, h + 3], 1.5);
            translate([0, 0, cap_flange - 0.01]) linear_extrude(face_t + cap_out + 0.01) rounded_rect([w - 0.2, h - 0.2], 1);
        }
        top = cap_flange + face_t + cap_out;
        if (len(txt) > 0) translate([0, 0, top - 0.5]) linear_extrude(1)
            text(txt, size = tsize, font = label_font, halign = "center", valign = "center");
        if (arrow) translate([0, 0, top - 0.5]) linear_extrude(1) flip_arrow(min(w - 3, 7), 3);
        // slight dish
        translate([0, 0, top + 6 - 0.3]) scale([w / 8, h / 8, 1]) sphere(r = 6, $fn = 32);
    }
}

// ---------- knobs (printed top-down: the grip face on the bed is the knob's front)
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

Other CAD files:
parts/mixture/stl/housing.stl
parts/panel-extras/stl/stem_clip.stl
parts/parking-brake/panel-template/parking_brake_cutout.dxf
parts/parking-brake/stl/housing.stl
common/push_pull.scad
common/sim_common.scad
panel/c172_panel.scad
panel/dashboard/cnc/lower_1.dxf
panel/dashboard/cnc/lower_1_back.dxf
panel/dashboard/cnc/lower_2.dxf
panel/dashboard/cnc/lower_2_back.dxf
panel/dashboard/cnc/pedestal_floor.dxf
panel/dashboard/cnc/splice.dxf
panel/dashboard/cnc/splice_small.dxf
panel/dashboard/cnc/upper_1.dxf
panel/dashboard/cnc/upper_1_back.dxf
panel/dashboard/cnc/upper_2.dxf
panel/dashboard/cnc/upper_2_back.dxf
panel/dashboard/stl/glareshield_1.stl
panel/dashboard/stl/glareshield_2.stl
panel/dashboard/stl/glareshield_3.stl
panel/dashboard/stl/glareshield_4.stl
panel/dashboard/stl/pedestal_face.stl
panel/dashboard/stl/pedestal_floor.stl
panel/dashboard/stl/splice.stl
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

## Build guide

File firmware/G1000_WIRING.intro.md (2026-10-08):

# G1000 dashboard: electronics and MSFS setup

The dashboard uses four small boards, all plugged into one powered USB hub:

| Board | Runs | Handles |
|---|---|---|
| Arduino Pro Micro | [`c172_panel.ino`](c172_panel/c172_panel.ino) (a USB joystick) | Throttle, mixture, prop, flaps (axes), parking brake, fuel selector, trim wheel |
| Arduino Mega 2560 #1 | [MobiFlight](https://www.mobiflight.com) | PFD bezel: 32 keys, 9 knobs |
| Arduino Mega 2560 #2 | MobiFlight | MFD bezel: same as the PFD |
| Arduino Mega 2560 #3 | MobiFlight | Audio panel, C-post switches, lights/dimming panel, ignition key |

As far as I know, your GP-Wiz is a button-only board. It could take some of the board 3 switches if you like, but the knobs (encoders) and dimmers need the Megas.

## Wiring rules (all boards)

- **Switches and keys:** wire between the pin and **GND**. MobiFlight turns on the internal pull-ups, so you don't need resistors.
- **Encoders:** A and B to the two listed pins, the middle pin (C) to **GND**. On the ALPS dual-shaft EC11, wire the outer and inner encoders separately; they're listed as two encoders below.
- **Encoder push switches** (VOL, HDG, RANGE): the two switch legs go to the listed pin and GND.
- **Rockers and toggles:** use the common terminal and the ON terminal.
- **Grounds:** run one ground bus per bezel (a bare wire along the back of the switch plate) and solder every switch's ground leg to it. That's about 65 wires per bezel, so ribbon cable or Dupont jumpers to the Mega headers keep it tidy.

## Screens

The PFD and MFD screens are two 10.4" 4:3 1024×768 LCD panels with HDMI driver boards (the usual "10.4 inch LCD + HDMI controller kit"). In MSFS 2024, right-Alt + click the PFD to pop it out, drag it to the PFD screen and make it full screen. Do the same for the MFD. The screen cradles hold the LCD by its edges, so measure your panel and set `lcd_w`, `lcd_h` and `lcd_t` in `parts/g1000-gdu/gdu1040.scad` before printing them.

## MobiFlight events

In MobiFlight, add each input with **Action type: MSFS2020 - Events (Presets)** (it works with MSFS 2024) and search the HubHop preset list for the control. Look in the "Cessna 172 / G1000" or "Generic AS1000" groups. Suggested presets:

| Control | Preset / event to search for |
|---|---|
| Softkeys | `AS1000 PFD Softkey 1..12` / `AS1000 MFD Softkey 1..12` |
| NAV, COM, FMS knobs | `AS1000 PFD NAV Large / Small Inc / Dec`, `... COM ...`, `... FMS Upper / Lower ...` |
| NAV / COM flip keys | `AS1000 PFD NAV Switch`, `AS1000 PFD COM Switch` |
| HDG, CRS, BARO | `Heading bug inc / dec`, `VOR1 OBI inc / dec`, `Kohlsman inc / dec` (push HDG = heading bug sync) |
| RANGE | `AS1000 PFD/MFD Range inc / dec` |
| FMS keys | `AS1000 PFD/MFD DirectTo, Menu, FPL, PROC, CLR, ENT` |
| AP keys | `AP master`, `Flight director`, `AP heading hold`, `AP altitude hold`, `AP NAV1 hold`, `AP approach hold`, `AP back course`, `AP VS hold`, `FLC`, `VS / pitch up / down`, `VNAV` |
| ALT knob | `AP altitude var inc / dec` (outer = 1000 ft, inner = 100 ft) |
| MASTER ALT / BAT | `Alternator set`, `Master battery set` (bind the press as on and the release as off) |
| AVIONICS BUS 1 / 2 | `Avionics master 1 / 2 set` |
| Lights | `Beacon / Landing / Taxi / Nav / Strobe lights set` |
| FUEL PUMP, PITOT HEAT | `Fuel pump set`, `Pitot heat set` |
| Ignition | `Magneto off / right / left / both / start` |
| Dimmers | `Light potentiometer set` (analog input), one index per knob |
| Audio panel | `COM1 / COM2 transmit select`, `COM receive`, `NAV1 / NAV2 / ADF / DME / MKR audio` |

Preset names in HubHop change now and then, so search by these words. The events above are the standard MSFS ones I expect; check each one on the ground before relying on it.

The Pro Micro shows up as a normal joystick. In MSFS, bind X to *Throttle axis*, Y to *Mixture axis*, Z to *Propeller axis* and Rx to *Flaps axis*. The buttons are listed in [`README.md`](README.md).

## Pin maps

The tables below are generated by `make_pinmaps.py`. Any free pin works; these are just a tidy starting point.

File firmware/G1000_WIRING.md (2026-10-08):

# G1000 dashboard: electronics and MSFS setup

The dashboard uses four small boards, all plugged into one powered USB hub:

| Board | Runs | Handles |
|---|---|---|
| Arduino Pro Micro | [`c172_panel.ino`](c172_panel/c172_panel.ino) (a USB joystick) | Throttle, mixture, prop, flaps (axes), parking brake, fuel selector, trim wheel |
| Arduino Mega 2560 #1 | [MobiFlight](https://www.mobiflight.com) | PFD bezel: 32 keys, 9 knobs |
| Arduino Mega 2560 #2 | MobiFlight | MFD bezel: same as the PFD |
| Arduino Mega 2560 #3 | MobiFlight | Audio panel, C-post switches, lights/dimming panel, ignition key |

As far as I know, your GP-Wiz is a button-only board. It could take some of the board 3 switches if you like, but the knobs (encoders) and dimmers need the Megas.

## Wiring rules (all boards)

- **Switches and keys:** wire between the pin and **GND**. MobiFlight turns on the internal pull-ups, so you don't need resistors.
- **Encoders:** A and B to the two listed pins, the middle pin (C) to **GND**. On the ALPS dual-shaft EC11, wire the outer and inner encoders separately; they're listed as two encoders below.
- **Encoder push switches** (VOL, HDG, RANGE): the two switch legs go to the listed pin and GND.
- **Rockers and toggles:** use the common terminal and the ON terminal.
- **Grounds:** run one ground bus per bezel (a bare wire along the back of the switch plate) and solder every switch's ground leg to it. That's about 65 wires per bezel, so ribbon cable or Dupont jumpers to the Mega headers keep it tidy.

## Screens

The PFD and MFD screens are two 10.4" 4:3 1024×768 LCD panels with HDMI driver boards (the usual "10.4 inch LCD + HDMI controller kit"). In MSFS 2024, right-Alt + click the PFD to pop it out, drag it to the PFD screen and make it full screen. Do the same for the MFD. The screen cradles hold the LCD by its edges, so measure your panel and set `lcd_w`, `lcd_h` and `lcd_t` in `parts/g1000-gdu/gdu1040.scad` before printing them.

## MobiFlight events

In MobiFlight, add each input with **Action type: MSFS2020 - Events (Presets)** (it works with MSFS 2024) and search the HubHop preset list for the control. Look in the "Cessna 172 / G1000" or "Generic AS1000" groups. Suggested presets:

| Control | Preset / event to search for |
|---|---|
| Softkeys | `AS1000 PFD Softkey 1..12` / `AS1000 MFD Softkey 1..12` |
| NAV, COM, FMS knobs | `AS1000 PFD NAV Large / Small Inc / Dec`, `... COM ...`, `... FMS Upper / Lower ...` |
| NAV / COM flip keys | `AS1000 PFD NAV Switch`, `AS1000 PFD COM Switch` |
| HDG, CRS, BARO | `Heading bug inc / dec`, `VOR1 OBI inc / dec`, `Kohlsman inc / dec` (push HDG = heading bug sync) |
| RANGE | `AS1000 PFD/MFD Range inc / dec` |
| FMS keys | `AS1000 PFD/MFD DirectTo, Menu, FPL, PROC, CLR, ENT` |
| AP keys | `AP master`, `Flight director`, `AP heading hold`, `AP altitude hold`, `AP NAV1 hold`, `AP approach hold`, `AP back course`, `AP VS hold`, `FLC`, `VS / pitch up / down`, `VNAV` |
| ALT knob | `AP altitude var inc / dec` (outer = 1000 ft, inner = 100 ft) |
| MASTER ALT / BAT | `Alternator set`, `Master battery set` (bind the press as on and the release as off) |
| AVIONICS BUS 1 / 2 | `Avionics master 1 / 2 set` |
| Lights | `Beacon / Landing / Taxi / Nav / Strobe lights set` |
| FUEL PUMP, PITOT HEAT | `Fuel pump set`, `Pitot heat set` |
| Ignition | `Magneto off / right / left / both / start` |
| Dimmers | `Light potentiometer set` (analog input), one index per knob |
| Audio panel | `COM1 / COM2 transmit select`, `COM receive`, `NAV1 / NAV2 / ADF / DME / MKR audio` |

Preset names in HubHop change now and then, so search by these words. The events above are the standard MSFS ones I expect; check each one on the ground before relying on it.

The Pro Micro shows up as a normal joystick. In MSFS, bind X to *Throttle axis*, Y to *Mixture axis*, Z to *Propeller axis* and Rx to *Flaps axis*. The buttons are listed in [`README.md`](README.md).

## Pin maps

The tables below are generated by `make_pinmaps.py`. Any free pin works; these are just a tidy starting point.

## Board 1: PFD bezel

One Arduino Mega 2560 behind the PFD. 32 keys + 9 knobs (5 of them dual).

64 pins used of 67.

| Input | Type | Mega pin(s) |
|---|---|---|
| PFD NAV VOL (turn) | Encoder | D2 (A), D3 (B) |
| PFD NAV VOL push (ID) | Button / switch | D4 |
| PFD NAV outer knob | Encoder | D5 (A), D6 (B) |
| PFD NAV inner knob | Encoder | D7 (A), D8 (B) |
| PFD NAV flip key | Button / switch | D9 |
| PFD HDG knob | Encoder | D10 (A), D11 (B) |
| PFD HDG push (sync) | Button / switch | D12 |
| PFD ALT outer knob | Encoder | D14 (A), D15 (B) |
| PFD ALT inner knob | Encoder | D16 (A), D17 (B) |
| PFD COM VOL (turn) | Encoder | D18 (A), D19 (B) |
| PFD COM VOL push (squelch) | Button / switch | D20 |
| PFD COM outer knob | Encoder | D21 (A), D22 (B) |
| PFD COM inner knob | Encoder | D23 (A), D24 (B) |
| PFD COM flip key | Button / switch | D25 |
| PFD CRS knob (inner) | Encoder | D26 (A), D27 (B) |
| PFD BARO knob (outer) | Encoder | D28 (A), D29 (B) |
| PFD RANGE knob | Encoder | D30 (A), D31 (B) |
| PFD RANGE push (pan) | Button / switch | D32 |
| PFD FMS outer knob | Encoder | D33 (A), D34 (B) |
| PFD FMS inner knob | Encoder | D35 (A), D36 (B) |
| PFD softkey 1 | Button / switch | D37 |
| PFD softkey 2 | Button / switch | D38 |
| PFD softkey 3 | Button / switch | D39 |
| PFD softkey 4 | Button / switch | D40 |
| PFD softkey 5 | Button / switch | D41 |
| PFD softkey 6 | Button / switch | D42 |
| PFD softkey 7 | Button / switch | D43 |
| PFD softkey 8 | Button / switch | D44 |
| PFD softkey 9 | Button / switch | D45 |
| PFD softkey 10 | Button / switch | D46 |
| PFD softkey 11 | Button / switch | D47 |
| PFD softkey 12 | Button / switch | D48 |
| PFD AP | Button / switch | D49 |
| PFD FD | Button / switch | D50 |
| PFD HDG | Button / switch | D51 |
| PFD ALT | Button / switch | D52 |
| PFD NAV | Button / switch | D53 |
| PFD VNV | Button / switch | A0 |
| PFD APR | Button / switch | A1 |
| PFD BC | Button / switch | A2 |
| PFD VS | Button / switch | A3 |
| PFD NOSE UP | Button / switch | A4 |
| PFD FLC | Button / switch | A5 |
| PFD NOSE DN | Button / switch | A6 |
| PFD DIRECT-TO | Button / switch | A7 |
| PFD MENU | Button / switch | A8 |
| PFD FPL | Button / switch | A9 |
| PFD PROC | Button / switch | A10 |
| PFD CLR | Button / switch | A11 |
| PFD ENT | Button / switch | A12 |

## Board 2: MFD bezel

Identical to board 1, for the MFD. Name it differently in MobiFlight (e.g. "MFD").

64 pins used of 67.

| Input | Type | Mega pin(s) |
|---|---|---|
| MFD NAV VOL (turn) | Encoder | D2 (A), D3 (B) |
| MFD NAV VOL push (ID) | Button / switch | D4 |
| MFD NAV outer knob | Encoder | D5 (A), D6 (B) |
| MFD NAV inner knob | Encoder | D7 (A), D8 (B) |
| MFD NAV flip key | Button / switch | D9 |
| MFD HDG knob | Encoder | D10 (A), D11 (B) |
| MFD HDG push (sync) | Button / switch | D12 |
| MFD ALT outer knob | Encoder | D14 (A), D15 (B) |
| MFD ALT inner knob | Encoder | D16 (A), D17 (B) |
| MFD COM VOL (turn) | Encoder | D18 (A), D19 (B) |
| MFD COM VOL push (squelch) | Button / switch | D20 |
| MFD COM outer knob | Encoder | D21 (A), D22 (B) |
| MFD COM inner knob | Encoder | D23 (A), D24 (B) |
| MFD COM flip key | Button / switch | D25 |
| MFD CRS knob (inner) | Encoder | D26 (A), D27 (B) |
| MFD BARO knob (outer) | Encoder | D28 (A), D29 (B) |
| MFD RANGE knob | Encoder | D30 (A), D31 (B) |
| MFD RANGE push (pan) | Button / switch | D32 |
| MFD FMS outer knob | Encoder | D33 (A), D34 (B) |
| MFD FMS inner knob | Encoder | D35 (A), D36 (B) |
| MFD softkey 1 | Button / switch | D37 |
| MFD softkey 2 | Button / switch | D38 |
| MFD softkey 3 | Button / switch | D39 |
| MFD softkey 4 | Button / switch | D40 |
| MFD softkey 5 | Button / switch | D41 |
| MFD softkey 6 | Button / switch | D42 |
| MFD softkey 7 | Button / switch | D43 |
| MFD softkey 8 | Button / switch | D44 |
| MFD softkey 9 | Button / switch | D45 |
| MFD softkey 10 | Button / switch | D46 |
| MFD softkey 11 | Button / switch | D47 |
| MFD softkey 12 | Button / switch | D48 |
| MFD AP | Button / switch | D49 |
| MFD FD | Button / switch | D50 |
| MFD HDG | Button / switch | D51 |
| MFD ALT | Button / switch | D52 |
| MFD NAV | Button / switch | D53 |
| MFD VNV | Button / switch | A0 |
| MFD APR | Button / switch | A1 |
| MFD BC | Button / switch | A2 |
| MFD VS | Button / switch | A3 |
| MFD NOSE UP | Button / switch | A4 |
| MFD FLC | Button / switch | A5 |
| MFD NOSE DN | Button / switch | A6 |
| MFD DIRECT-TO | Button / switch | A7 |
| MFD MENU | Button / switch | A8 |
| MFD FPL | Button / switch | A9 |
| MFD PROC | Button / switch | A10 |
| MFD CLR | Button / switch | A11 |
| MFD ENT | Button / switch | A12 |

## Board 3: audio panel, switch panels, ignition

One Mega for everything else that is a switch. The four dimmer pots go to A12-A15 as MobiFlight analog inputs (pin numbers shown above stop before them).

45 pins used of 67.

| Input | Type | Mega pin(s) |
|---|---|---|
| GMA COM1 MIC | Button / switch | D2 |
| GMA COM1 | Button / switch | D3 |
| GMA COM2 MIC | Button / switch | D4 |
| GMA COM2 | Button / switch | D5 |
| GMA COM3 MIC | Button / switch | D6 |
| GMA COM3 | Button / switch | D7 |
| GMA COM1/2 | Button / switch | D8 |
| GMA TEL | Button / switch | D9 |
| GMA PA | Button / switch | D10 |
| GMA SPKR | Button / switch | D11 |
| GMA MKR/MUTE | Button / switch | D12 |
| GMA HI SENS | Button / switch | D14 |
| GMA DME | Button / switch | D15 |
| GMA NAV1 | Button / switch | D16 |
| GMA ADF | Button / switch | D17 |
| GMA NAV2 | Button / switch | D18 |
| GMA AUX | Button / switch | D19 |
| GMA MAN SQ | Button / switch | D20 |
| GMA PLAY | Button / switch | D21 |
| GMA PILOT | Button / switch | D22 |
| GMA COPLT | Button / switch | D23 |
| GMA volume knob | Encoder | D24 (A), D25 (B) |
| GMA volume push | Button / switch | D26 |
| GMA DISPLAY BACKUP | Button / switch | D27 |
| STBY BATT ON | Button / switch | D28 |
| STBY BATT TEST | Button / switch | D29 |
| STBY BATT test light | LED output | D30 |
| MASTER ALT | Button / switch | D31 |
| MASTER BAT | Button / switch | D32 |
| AVIONICS BUS 1 | Button / switch | D33 |
| AVIONICS BUS 2 | Button / switch | D34 |
| BEACON light | Button / switch | D35 |
| LAND light | Button / switch | D36 |
| TAXI light | Button / switch | D37 |
| NAV light | Button / switch | D38 |
| STROBE light | Button / switch | D39 |
| FUEL PUMP | Button / switch | D40 |
| PITOT HEAT | Button / switch | D41 |
| CABIN PWR 12V | Button / switch | D42 |
| Ignition OFF | Button / switch | D43 |
| Ignition R | Button / switch | D44 |
| Ignition L | Button / switch | D45 |
| Ignition BOTH | Button / switch | D46 |
| Ignition START | Button / switch | D47 |

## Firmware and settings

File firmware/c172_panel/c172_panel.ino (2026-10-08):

// C172 home-sim panel -> one USB game controller
//
// Board:   Arduino Pro Micro (ATmega32U4) or Leonardo
// Library: "Joystick" by Matthew Heironimus (ArduinoJoystickLibrary)
//          https://github.com/MHeironimus/ArduinoJoystickLibrary
//
// Shows up in Windows / MSFS as a joystick with 4 axes and 16 buttons:
//
//   X axis  throttle   (slide pot wiper -> A0)
//   Y axis  mixture    (slide pot wiper -> A1)
//   Z axis  prop       (slide pot wiper -> A2, optional)
//   Rx axis flaps      (flap lever slide pot wiper -> A3, optional)
//
//   Button 1   parking brake SET      (held while the handle is out)
//   Button 2   parking brake - pulse when it becomes SET
//   Button 3   parking brake - pulse when it becomes RELEASED
//   Button 4   fuel selector LEFT     (held)
//   Button 5   fuel selector BOTH     (held)
//   Button 6   fuel selector RIGHT    (held)
//   Button 7   fuel selector OFF      (held, only if you built has_off)
//   Button 8   trim NOSE DOWN         (one pulse per click of the wheel)
//   Button 9   trim NOSE UP           (one pulse per click of the wheel)
//
// Wiring: every switch goes between its pin and GND (internal pull-ups are
// used). Pots: ends to VCC and GND, wiper to the analog pin.
//
// Calibration: the levers only use part of a long slide pot's travel (about
// 60 mm of the 128 mm pot's 100 mm). The sketch learns each axis's range by
// itself: after flashing, move every lever end to end once. The range is saved
// in EEPROM, so it survives unplugging. Set RESET_CALIBRATION = true, flash,
// then set it back to false and flash again to start over.
//
//   Pin 2  parking brake microswitch (COM -> GND, NC -> pin 2)
//   Pin 3  fuel selector position LEFT   (rotary switch common -> GND)
//   Pin 4  fuel selector position BOTH
//   Pin 5  fuel selector position RIGHT
//   Pin 6  fuel selector position OFF
//   Pin 7  trim encoder A
//   Pin 8  trim encoder B   (encoder C / middle pin -> GND)

#include <Joystick.h>
#include <EEPROM.h>

// ---- settings ---------------------------------------------------------------
const bool HAS_PROP = false;        // true if you built the prop control
const bool HAS_FLAPS = false;       // true if you built the flap lever
const bool REVERSE_THROTTLE = false;
const bool REVERSE_MIXTURE  = false;
const bool REVERSE_PROP     = false;
const bool REVERSE_FLAPS    = false;
const bool REVERSE_TRIM     = false;  // swap if nose-down/up come out backwards
const int  STEPS_PER_DETENT = 4;      // EC11 encoders: usually 4 (try 2 if it skips)
const int  PULSE_MS         = 40;     // how long each trim / brake pulse is held
const bool RESET_CALIBRATION = false; // true = forget the learned lever ranges

// ---- pins -------------------------------------------------------------------
const int PIN_THROTTLE = A0, PIN_MIXTURE = A1, PIN_PROP = A2, PIN_FLAPS = A3;
const int PIN_BRAKE = 2;
const int PIN_FUEL[4] = {3, 4, 5, 6};     // LEFT, BOTH, RIGHT, OFF
const int PIN_ENC_A = 7, PIN_ENC_B = 8;

Joystick_ Joystick(JOYSTICK_DEFAULT_REPORT_ID, JOYSTICK_TYPE_JOYSTICK,
                   16, 0,                 // buttons, hat switches
                   true, true, true,      // X, Y, Z
                   true, false, false,    // Rx, Ry, Rz
                   false, false,          // rudder, throttle
                   false, false, false);  // accelerator, brake, steering

// Simple smoothing so the axes don't jitter
int smooth(int pin, float &state) {
  state += (analogRead(pin) - state) * 0.2;
  return (int)(state + 0.5);
}

// ---- self-calibrating axes: each one stretches the part of the pot it uses
// to the full 0..1023. The range only grows, and is saved in EEPROM.
const int CAL_ADDR = 0, CAL_MAGIC = 0x172C;
const int DEAD = 6;                 // a little dead zone at each end so 0 % / 100 % are easy to hit
int calLo[4], calHi[4];
bool calDirty = false;
unsigned long calSaveAt = 0;

void loadCalibration() {
  int magic;
  EEPROM.get(CAL_ADDR, magic);
  if (magic == CAL_MAGIC && !RESET_CALIBRATION) {
    EEPROM.get(CAL_ADDR + 2, calLo);
    EEPROM.get(CAL_ADDR + 2 + sizeof(calLo), calHi);
  } else {
    for (int i = 0; i < 4; i++) { calLo[i] = 450; calHi[i] = 570; }   // grows as you move the levers
  }
}
void saveCalibration() {
  EEPROM.put(CAL_ADDR, CAL_MAGIC);
  EEPROM.put(CAL_ADDR + 2, calLo);
  EEPROM.put(CAL_ADDR + 2 + sizeof(calLo), calHi);
}
int calibrated(int i, int raw) {
  if (raw < calLo[i] - 3) { calLo[i] = raw; calDirty = true; }
  if (raw > calHi[i] + 3) { calHi[i] = raw; calDirty = true; }
  long v = map(raw, calLo[i] + DEAD, calHi[i] - DEAD, 0, 1023);
  return (int)constrain(v, 0L, 1023L);
}

float sThr = 0, sMix = 0, sProp = 0, sFlap = 0;
int lastBrake = -1;
unsigned long brakePulseUntil[2] = {0, 0};   // [0]=set pulse, [1]=release pulse

// Trim encoder
int encLast = 0, encCount = 0;
int trimPending = 0;                          // + = nose down pulses, - = nose up
unsigned long trimPulseUntil = 0, trimGapUntil = 0;
int trimButton = -1;

const int8_t QDEC[16] = {0, -1, 1, 0, 1, 0, 0, -1, -1, 0, 0, 1, 0, 1, -1, 0};

void readEncoder() {
  int s = (digitalRead(PIN_ENC_A) << 1) | digitalRead(PIN_ENC_B);
  encCount += QDEC[(encLast << 2) | s];
  encLast = s;
  if (encCount >= STEPS_PER_DETENT)  { trimPending += REVERSE_TRIM ? -1 : 1; encCount = 0; }
  if (encCount <= -STEPS_PER_DETENT) { trimPending += REVERSE_TRIM ? 1 : -1; encCount = 0; }
}

void setup() {
  pinMode(PIN_BRAKE, INPUT_PULLUP);
  for (int i = 0; i < 4; i++) pinMode(PIN_FUEL[i], INPUT_PULLUP);
  pinMode(PIN_ENC_A, INPUT_PULLUP);
  pinMode(PIN_ENC_B, INPUT_PULLUP);
  encLast = (digitalRead(PIN_ENC_A) << 1) | digitalRead(PIN_ENC_B);

  Joystick.setXAxisRange(0, 1023);
  Joystick.setYAxisRange(0, 1023);
  Joystick.setZAxisRange(0, 1023);
  Joystick.setRxAxisRange(0, 1023);
  Joystick.begin(false);
  loadCalibration();
  sThr = analogRead(PIN_THROTTLE); sMix = analogRead(PIN_MIXTURE); sProp = analogRead(PIN_PROP); sFlap = analogRead(PIN_FLAPS);
}

void loop() {
  unsigned long now = millis();

  // ---- axes
  int t = calibrated(0, smooth(PIN_THROTTLE, sThr));
  int m = calibrated(1, smooth(PIN_MIXTURE, sMix));
  int p = HAS_PROP ? calibrated(2, smooth(PIN_PROP, sProp)) : 1023;
  Joystick.setXAxis(REVERSE_THROTTLE ? 1023 - t : t);
  Joystick.setYAxis(REVERSE_MIXTURE  ? 1023 - m : m);
  Joystick.setZAxis(REVERSE_PROP     ? 1023 - p : p);
  int fl = HAS_FLAPS ? calibrated(3, smooth(PIN_FLAPS, sFlap)) : 0;
  // save a grown range once the levers have been still for 2 s (saves EEPROM wear)
  if (calDirty) { calSaveAt = now + 2000; calDirty = false; }
  if (calSaveAt && now > calSaveAt) { saveCalibration(); calSaveAt = 0; }
  Joystick.setRxAxis(REVERSE_FLAPS   ? 1023 - fl : fl);

  // ---- parking brake (held + edge pulses)
  int brake = digitalRead(PIN_BRAKE) == LOW;
  if (lastBrake != -1 && brake != lastBrake) brakePulseUntil[brake ? 0 : 1] = now + PULSE_MS;
  lastBrake = brake;
  Joystick.setButton(0, brake);
  Joystick.setButton(1, now < brakePulseUntil[0]);
  Joystick.setButton(2, now < brakePulseUntil[1]);

  // ---- fuel selector
  for (int i = 0; i < 4; i++) Joystick.setButton(3 + i, digitalRead(PIN_FUEL[i]) == LOW);

  // ---- trim wheel: turn each detent into one button pulse
  readEncoder();
  if (trimButton >= 0 && now >= trimPulseUntil) {
    Joystick.setButton(trimButton, 0);
    trimButton = -1;
    trimGapUntil = now + PULSE_MS / 2;
  }
  if (trimButton < 0 && trimPending != 0 && now >= trimGapUntil) {
    trimButton = trimPending > 0 ? 7 : 8;
    trimPending += trimPending > 0 ? -1 : 1;
    Joystick.setButton(trimButton, 1);
    trimPulseUntil = now + PULSE_MS;
  }

  Joystick.sendState();
  // keep polling the encoder quickly between USB reports
  for (int i = 0; i < 20; i++) { readEncoder(); delayMicroseconds(100); }
}

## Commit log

2026-10-08 Add parametric C172 parking brake control
    Pull-and-twist T-handle with bayonet detent, return spring, microswitch
    sensor, panel bezel and cutout template. Shared panel settings in common/.
    Claude-Session: https://claude.ai/code/session_011ZoknF5M6U8HtxFZjvmYRS
    [bezel.stl, handle.stl, housing.stl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]
2026-10-08 Realistic C172 parts: parking brake L-handle, throttle/mixture/prop, trim wheel, fuel selector, printable panel
    - Parking brake redone to match the real L-shaped lever (pull, rotate down
    to set), flush 4-bolt panel mount with captive nuts, small escutcheon
    - Shared push-pull mechanism (8mm rod, O-ring friction, 60mm slide pot)
    with real-style knobs: throttle (smooth + knurled friction nut), mixture
    (red ribbed vernier w/ button), prop (blue crenellated)
    - Elevator trim wheel: ridged wheel on 608 bearings, 3:1 gear to EC11
    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
    [bezel.stl, c172_panel.scad, carriage.stl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]
2026-10-08 Add 'Moving the controls' guide, layout map and layout checks
    - Main README: how to reposition every control on the printable panel
    (Customizer and command line), settings table, tips
    - panel: layout_map view/image showing the coordinates of each control
    - panel: warnings for overlapping controls, controls off the edge and
    tile seams through a control
    - mixture position split into two plain settings so it shows in the
    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
    [c172_panel.scad, lower_tile_1.stl, lower_tile_2.stl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]
2026-10-08 Add animations of every control working to the READMEs
    - docs/anim/*.gif: each control operating, from the seat and from behind
    the panel with see-through housings (parking brake set/release,
    throttle/mixture/prop push-pull, trim wheel + encoder gear, fuel
    selector LEFT/BOTH/RIGHT with switch gear)
    - 'anim' and 'ghost' settings drive the animations in each .scad
    - scripts/make_gifs.py renders them
    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
    [fuel_selector.scad, parking_brake.scad, push_pull.scad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]
2026-10-08 Add the full Cessna 172S G1000 dashboard
    - panel/g1000_dashboard.scad: shortened (810 mm) 172S NAV III panel at real
    scale, 12 tiles for a 250 mm bed (grey upper / black lower), glareshield,
    pedestal, Moza AY210 yoke opening + clearance check, layout settings
    - parts/g1000-gdu: working GDU 1040 PFD/MFD bezel, real size and key layout
    (32 keys on 6x6 tactile switches, 9 knobs on EC11 / dual EC11), 10.4"
    1024x768 screen in a cradle on the panel back, split for small beds
    - parts/g1000-gma: working GMA 1347 audio panel
    - parts/switch-panel: C-post (STBY BATT, MASTER, AVIONICS) and
    lights/dimming plates for off-the-shelf rockers, toggles and pots
    - parts/standby-gauges: printed instrum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
    [avionics_lib.scad, caps_sheet.stl, carriage.stl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]
2026-10-08 Animate the dashboard parts and re-tile for a 305 mm bed
    - New README animations: flap lever, G1000 bezel, GMA audio panel,
    C-post / lights panels, ignition key
    - Dashboard tiles re-split for a QIDI Plus4 (305 mm): 9 tiles, 3 per row,
    separate seams per row, explicit splice plate positions (fixes pilot holes)
    - One-piece G1000 front plate and switch plate options
    - Ignition labels no longer overlap; breaker strips nudged to clear them
    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
    [avionics_lib.scad, c172_panel.scad, caps_sheet.stl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]
2026-10-08 Fit the 128 mm / 100 mm-travel slide pots
    - Throttle, mixture, prop: housing floor runs on under the longer pot;
    knob travel stays 60 mm (control_travel), pot size is a setting
    - Flap lever: narrow channels carry the pot ends; flap moved to [380, 60]
    on the dashboard so the pot clears the altimeter and the panel bottom
    - Pro Micro sketch learns each lever's range and saves it in EEPROM
    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
    [carriage.stl, dashboard_panel.dxf, escutcheon.stl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]
2026-10-08 Slide pot lever height 16 mm (Fielect 128 x 16mm)
    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
    [carriage.stl, escutcheon.stl, flap_lever.scad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]
2026-10-08 CNC router files for the dashboard; fit the Fielect pot's real size
    - panel/dashboard/cnc: layered DXF + SVG for cutting the panel from 1/4"
    plywood on an 800 x 400 router (FoxAlien XE-PRO 8040): 4 panel pieces,
    pedestal face and floor, splice plate; CUT / DRILL / ENGRAVE /
    COUNTERSINK layers, mirrored back-side pilot holes; scripts/make_cnc.py
    - Slide pot 128 x 15.7 x 6.9 mm, short lever: wider channel, carriage
    engagement follows the lever height
    - FUEL SHUTOFF label moved below its knob (it overlapped the trim slot)
    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
    [carriage.stl, escutcheon.stl, flap_lever.scad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]
2026-10-08 Join the dashboard pieces from the back
    - scripts/place_splices.py finds room for splice plates across every seam
    and row joint, clear of everything behind the panel, and writes
    panel/splices.scad (printed tiles and CNC pieces)
    - Two plate sizes (splice 34 x 70, splice_small 40 x 22); blind pilot holes
    in the tiles / CNC back files; M3 x 8 screws for printed plates
    - Glareshield now split halfway along the upper tiles so it bridges the
    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
    [g1000_dashboard.scad, glareshield_1.stl, glareshield_2.stl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]
2026-10-12 Real-looking ignition key; AY210 front panel flush in the dashboard
    - Ignition: a key with a bitted blade and black head that pushes into a
    lock face (ignition_cylinder) on the switch shaft, in a chrome-look bezel
    - Dashboard: window for the Moza AY210's whole front face (from Moza's
    drawing: 243 / 215.8 x 111.3 mm, shaft 66 mm up), base slides in flush;
    printed moza_frame trims the window and ties the lower pieces to the panel
    - Lower panel re-laid round the window (brake, ignition, breakers left;
    ALT STATIC AIR and breakers right); lights panel up 3 mm; overlap checks
    - Narrow splice strip for tight joints; CNC pieces start at 0,0
    - READMEs, images and the ignition animation update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
2026-10-12 Working mechanical standby gauges; dual knob on the GMA 1347
    - Airspeed: needle on an X27.168 gauge stepper (zeroes on its stop)
    - Altimeter: 28BYJ-48 drives the 100-ft hand, printed 10:1 gear train the
    1000-ft hand on a tube; hall-sensor homing; EC11 baro knob in the bezel
    - Attitude: SG90 roll servo turns a frame, a second SG90 inside the horizon
    drum pitches it; fixed bank scale and aircraft symbol
    - Front case + rear housing per gauge, clamped by 4 long screws; new faces
    - Board 3 pin map and MobiFlight setup for the gauges
    - GMA 1347: dual concentric knob (ALPS dual EC11)
    - Panel extras image shows the new key; knob labels read the right way round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
2026-10-31 Use 5/16" rod for the push-pull controls; add a 3-control test plate that mounts on 8020 extrusion
2026-10-31 Zip the throttle, mixture and prop files for one-click download
    Claude-Session: https://claude.ai/code/session_014zeXVm6XyZtU5W4xqL5EKi
2026-10-31 Test plate: size for 40 mm extrusion, holes centred, housings clear
    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
2026-11-01 Push-pull controls: pot in a slide-in tray, single slot for the flat arm, full pot travel
    - Pot drops into a printed tray (open underneath for the pins, ribs so the
    edge tabs hang free) that slides into the housing from the back on ledges
    - Slot through the rear bushing block so the 9 mm arm passes when sliding in
    - Carriage has one 1.5 x 8.6 mm slot for the 8 x 1 mm arm instead of a plus
    - No zip ties: blocks hold the pot down, one M3 keeper screw across the back
    - Travel 96 mm, nearly the whole 100 mm of the Fielect 128 mm fader
    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
2026-11-01 Re-make the throttle, mixture and prop animations for the tray design
    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
2026-11-01 Add a simple U cradle for under the slide pot (20 mm wide, 4 mm base, 2 mm sides)
    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
2026-11-02 Short rod: rod stops in the carriage, carriage slides on the housing walls and tray
    The 5/16" rod now only runs from the knob through the front bushing into the
    carriage: 170 mm instead of 284 mm, nothing out the back. The carriage is
    guided by the housing walls and its skids ride on the tray walls; the rear
    block is just the end stop. rod_through = true brings back the long rod.
    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
2026-11-02 Top-locked carriage: lid with a dovetail groove, smaller carriage with a tongue
    A lid screws onto the housing (4x M3 x 10). The carriage's dovetail tongue
    rides in a groove under it, locking it side to side, up/down and against
    twisting, so the carriage no longer needs the walls or the tray to guide it
    and shrinks to 12 mm wide. Set screw is now M3 x 6 so it sits below the tongue.
    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
2026-11-02 Test panel: add parking brake, trim wheel, fuel hole, ignition key encoder and a Pro Micro box
    - Parking brake under the prop, trim wheel under the throttle
    - 12.5 mm fuel selector hole in the corner, outside the brake handle's swing
    - Ignition key (panel-extras lock + bezel) on an EC11 encoder, back pocket
    thins the plate to 2 mm for the short bushing, positions engraved
    - Pro Micro box screws on behind with 4 countersunk M3; plate stays flat
    - Plate 270 x 240 mm; checked: no collisions front or back, brake
    stowed/set/swinging, key OFF..START, extrusion strips clear
    Claude-Session: https://claude.ai/code/session_014zeXVm6XyZtU5W4x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
2026-11-02 Test panel: move the ignition key 16 mm further from the throttle, plate 286 mm wide
    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
2026-11-02 Split clamp carriage: two screws beside the tongue, heads sunk below the lid
    The carriage is now two halves that clamp the rod, held by 2x M3 x 14
    socket-head screws (one each side of the tongue) into nuts slid into the
    lower half. The heads sit in counterbores below the lid, so nothing sticks
    up into the groove. Only the carriage changes; housing, lid, tray and the
    170 mm rod are the same.
    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
2026-11-03 Pro Micro box: snap clip holds the board, wire cut-outs on three sides, USB opening lower and smaller
    Same outside size and screw holes, so it still fits the printed plate.
    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
2026-11-03 Pro Micro box: lips over the corners at the USB end, so the board is held at both ends
    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
2026-11-03 Pro Micro box: USB opening 1.6 mm taller at the top (bottom edge unchanged)
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2026-11-03 Pro Micro box: screw-down L clamp replaces the snap clip, USB opening 3 mm bigger on the rim side
    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
2026-11-06 G1000 GDU: thicker, flared switch-plate posts so they print solidly face down
    Posts go from 6 mm to 8 mm with a 45 degree flare to 10 mm where they meet
    the plate. Moved the bottom-right post (it clashed with softkey 12's cap
    flange) and the two lower side posts so the flare clears the key caps,
    screen window and panel opening. Moved the switch-plate wire exits so the
    posts no longer cover them. GMA posts unchanged (no room).
    Claude-Session: https://claude.ai/code/session_014zeXViXs9iSGqQDZZ9Ghcd
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
